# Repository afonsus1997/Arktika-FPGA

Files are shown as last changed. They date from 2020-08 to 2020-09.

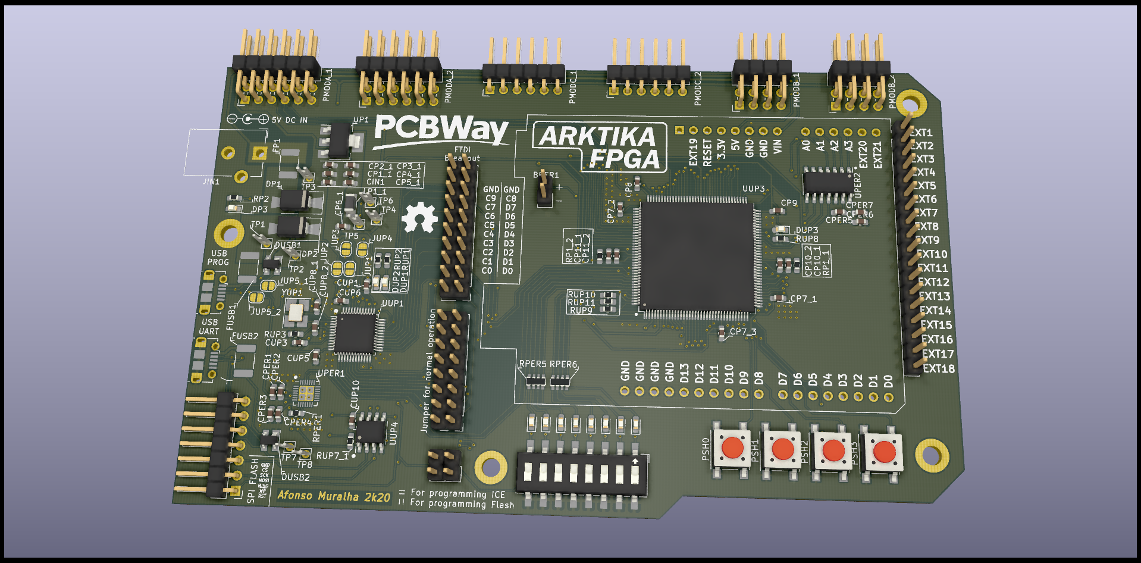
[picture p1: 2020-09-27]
Hardware/arktika-fpga/Media/render1.png

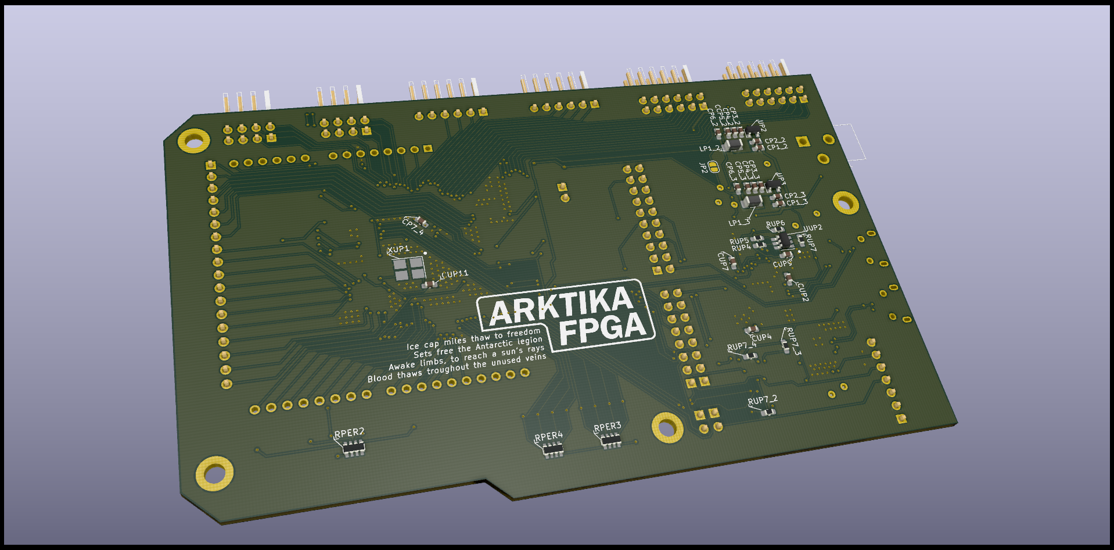
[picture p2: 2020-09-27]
Hardware/arktika-fpga/Media/render2.png

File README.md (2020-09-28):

Arktikalogo

### Project description

The Arktika FPGA is an open-source FPGA development board based on the ICE40 family (ICE40HX4K-TQ144).

### Main Features:

* 78 total user digital IO pins
  * 18 arduino uno compatible headers
  * 6 PMOD connectors (40 total pins)
    * 2x10pin
    * 2x6pin
    * 2x4pin
  * 18pin additional "EXT" connector
  * Buzzer connector
* 4 analog input channels
  * MCP3204 ADC
* 8 on-board LEDs
* 8 on-board DIP switches
* 4 on-board push buttons
* USB to UART bridge
* 50Mhz active crystal oscillator
* FT232hl USB bridge
  * Used for FPGA or flash programming
  * Breakout header for external use

### Known bugs
* V1.0
  * Flash CS line not connected (typo on net name)
  * Arduino connector mirrores (inteded for a shield and not the arduino footprint)
  * Wrong usb to uart bridge footprint (the footprint is correct, but it is not for the intended version of the IC)

### Development Log

* 27/09/20 (up to)
  * Finishing PCB design
  * Tested toolchain with some examples

### Screenshots and pictures

RenderFront

RanderBack

### Useful development links

[ICE40 Family datasheet](https://static6.arrow.com/aropdfconversion/5a93cb52911751cf0d102889c061f1e82d924150/3ice40lphxfamilydatasheet.pdf)

[ICE40 Hardware checklist](http://www.latticesemi.com/~/media/LatticeSemi/Documents/ApplicationNotes/IK/iCE40HardwareChecklist.pdf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)

[ICE40 Decoupling information](https://www.latticesemi.com/-/media/LatticeSemi/Documents/ApplicationNotes/PT/PowerDecouplingandBypassFilteringforProgrammableDevices.ashx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)

[ICE40 Programming information](http://www.latticesemi.com/dynamic/view_document.cfm?document_id=46502)

[PMOD Standard](http://digilentinc.com/Pmods/Digilent-Pmod_%20Interface_Specification.pdf)

###### Bonus

Q: What is arktika?

A: [Glad you asked!](https://en.wikipedia.org/wiki/Arktika_(1972_icebreaker))

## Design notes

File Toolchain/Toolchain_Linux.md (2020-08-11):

# Development Toolchain for linux

This document explains the development process for the Arktika FPGA
This document is a summary of the website 

Tools used:

* Yosys
    * For synthesis
* NextPNR
    * For Place and Route
* Icepack
    * For creating the bitstream
* Iceprog
    * For programing the FPGA/Flash

Special arguments for the iCE40-HX4K-TQ144 chip: 

  * nextpnr args:```--hx8k --package tq144:4k```
  * aranchne-pnr args:```-d 8k -P tq144:4k```
  * icetime args: ```-d hx8k```

### How to install the toolchain

Follow the instructions for [Summon-FPGA-Tools](https://github.com/esden/summon-fpga-tools). This will install all the needed tools.

### Toolchain usage example

Consider the (example name) example present on the examples folder.

* top.v
```
module top (input SW0, SW1, output LED0);
  assign LED0 = SW0 & SW1;
endmodule
```

The designators for the arktika io is present on the arktika.pcf file. This file must be included in the place and route process.

##### Using the command line:

* Synthesize the verilog code:
```
$ yosys -p 'synth_ice40 -top top -json top.json' top.v
```
* Do the place and route:
```
$ nextpnr-ice40 --hx8k --package tq144:4k  --pcf ../../Toolchain/arktika.pcf --json top.json --asc top.asc
```
* Create the bitstream
```
$ icepack top.asc top.bin
```
* Program the FPGA/Flash
```
$ iceprog top.bin
```

##### Using NextPNR GUI

* Synthesize the verilog code:
```
$ yosys -p 'synth_ice40 -top top -json top.json' top.v
```
* Do the place and route on the gui and export the .asc file:
```
$ nextpnr-ice40 --hx8k --package tq144:4k --json top.json --pcf ../../Toolchain/arktika.pcf --asc top.asc --gui
```
* Create the bitstream
```
$ icepack top.asc top.bin
```
* Program the FPGA/Flash
```
$ iceprog top.bin
```

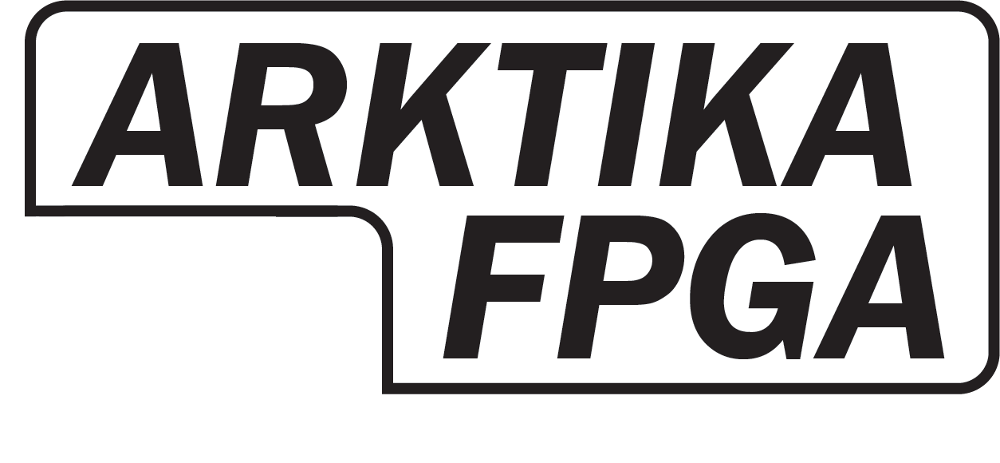
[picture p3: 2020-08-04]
Hardware/arktika-fpga/Media/arktikaFPGA_smaller.bmp

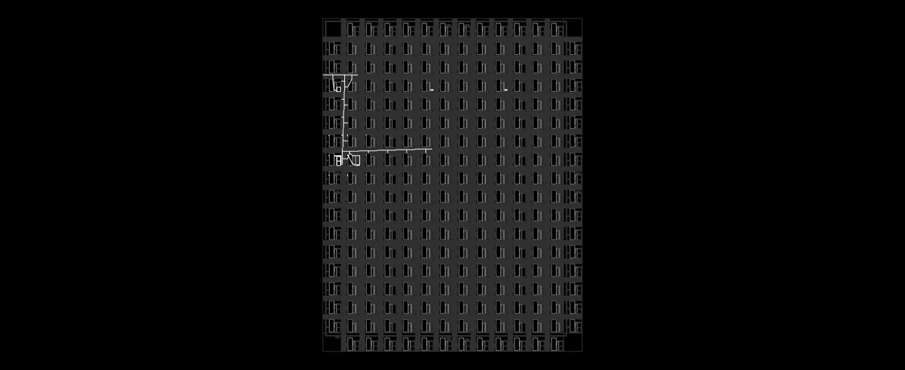
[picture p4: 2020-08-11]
Examples/Basic/top.png

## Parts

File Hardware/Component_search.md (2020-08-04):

### Power

Need 3.3V and 1.2V

* 3.3V
  * AMS1117
    * Have in stock, but may be too big/overkill
    * Gives some margin for driving more (and more demanding) external peripherals 

* 1.2V
  * MCP1812AT
    * 0.35eur
    * small
    * 300mA max
    * used on the icebreaker fpga and on the kefir fpga

### FPGA

Using the ICE40HX4K-TQ144

-----

# Component List

## Sheet Power

* JUSB1 - USB_B_ Micro – USB female connector.  <br>
  Datasheet:
  [Aliexpress](https://www.aliexpress.com/item/32795649371.html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,searchweb201602_,searchweb201603_) <br>
  
* DUSB1 – SP0503BAHT  - Array of protecting diodes.  <br>
  Datasheet:
  
* FUSB1 – Fuse for USB  <br>
  Datasheet:
  
* UP1 – AMS AMS1117-3.3   - Voltage Regulator 3.3V <br>
  [DigiKey](https://www.digikey.com/products/en/integrated-circuits-ics/pmic-display-drivers/729?k=AMS1117) <br>
  [Datasheet](https://media.digikey.com/pdf/Data%20Sheets/Austriamicrosystems%20PDFs/AS1117.pdf)
  
* UP2 e UP3 – Microchip MCP1812AT – Voltage Regulator 1.2V <br>
  [DigiKey](https://www.digikey.com/product-detail/en/microchip-technology/MCP1812AT-012-TT/MCP1812AT-012-TTTR-ND/9695617) <br>
  [Datasheet](https://ww1.microchip.com/downloads/en/DeviceDoc/MCP1811A-11B-12A-12B-Family-Data-Sheet-DS20006088C.pdf)
  
* LP1_1, LP1_2 e LP1_3 – Ferrite bead – High frequency filter. Murata BLM31B601S, BLM11B601SPB <br>
  [Mouser Electronics]()  <br>
  [Datasheet](https://pt.mouser.com/datasheet/2/281/c31e-794748.pdf)
                
## Sheet USB AND PROG

* Y? - 12 MHz Crystal <br>
  Datasheet:
  
* UUP1 – FTDI FT232H – USB to serial and SPI converter 3.3V. <br>
  [DigiKey](https://www.digikey.com/product-detail/en/ftdi-future-technology-devices-international-ltd/FT232HL-REEL/768-1101-1-ND/2614632) <br>
  [Datasheet](https://www.ftdichip.com/Support/Documents/DataSheets/ICs/DS_FT232H.pdf)
  
* UUP2 –  EEPROM 93LC56BT-I/OT – EEPROM to retain the configurations for the FTDI USB serial and SPI converter. <br>
  [DigiKey]( https://www.digikey.pt/product-detail/en/microchip-technology/93LC56BT-I-OT/93LC56BT-I-OTTR-ND/572825 )  <br>
  [Datasheet]( https://static6.arrow.com/aropdfconversion/88ae318f18f89e8680c0097a6b922f08efb41928/21794g.pdf )
  
* UP3E – FPGA LATICE ICE40HX4K-TQ144 <br>
  [DigiKey](https://www.digikey.com/products/en?keywords=ICE40HX4K-TQ144) <br>
  [Datasheet]()
  
* UUP4 – FLASH memory Winbond Electronics W25Q128JVS 3.3V- Flash to where is stored the FPGA configuration.<br>
  [DigiKey](https://www.digikey.com/product-detail/en/winbond-electronics/W25Q128JVSIQ-TR/W25Q128JVSIQTR-ND/5803944) <br>
  [Datasheet](https://www.winbond.com/resource-files/w25q128jv%20revf%2003272018%20plus.pdf)
                
## Sheet FPGA_IO
* Interfaces PMOD <br>
  PMOD1 – 2x10 <br>
  PMOD2 – 2x6 <br>
  PMOD3 – 2x4 <br>
  [Datasheet]()
* Interface Arduino UNO R3
* Interface common PINs FPGA
* Crystal oscillator ([arrow](https://www.arrow.com/en/products/abm8-50.000mhz-b1u-t/abracon), [arrow](https://www.arrow.com/en/products/ecs-500-10-33-rtn-tr/ecs-international), [arrow](https://www.arrow.com/en/products/7m-50.000maaj-t/txc-corporation), [arrow](https://www.arrow.com/en/products/ase2-50.000mhz-et/abracon), [arrow](https://www.arrow.com/en/products/ase2-50.000mhz-et/abracon))

## Sheet FPGA_PERIPHS

* JUSB2 – USB_B_MICRO – 2º USB female connector for serial to USB output/input. <br>
  Datasheet:
  
* U? - Silicon Labs CP2102N-A01-GQFN28 – 2º Converter USB Serial 3.3V. (end of life component) <br>
  [DigiKey](https://www.digikey.com/product-detail/en/silicon-labs/CP2102N-A01-GQFN28/336-3694-ND/6012519) <br>
  [Datasheet](https://media.digikey.com/pdf/Data%20Sheets/Silicon%20Laboratories%20PDFs/CP2102N_Rev.1.3_DS.pdf)
  
* U? – Microchip ADC  MCP3204 – 12 bit’s ADC, 100KS/s, 4 channels, SPI. <br>
  [Digikey](https://www.digikey.com/product-detail/en/microchip-technology/MCP3204-CI-SL/MCP3204-CI-SL-ND/305927) <br>
  [Datasheet](https://www.digikey.com/htmldatasheets/production/48382/0/0/1/mcp3204-3208.html)

* SW? – SW_DIP_x08 <br>
  Datasheet:
  
* And several resistors arrays.

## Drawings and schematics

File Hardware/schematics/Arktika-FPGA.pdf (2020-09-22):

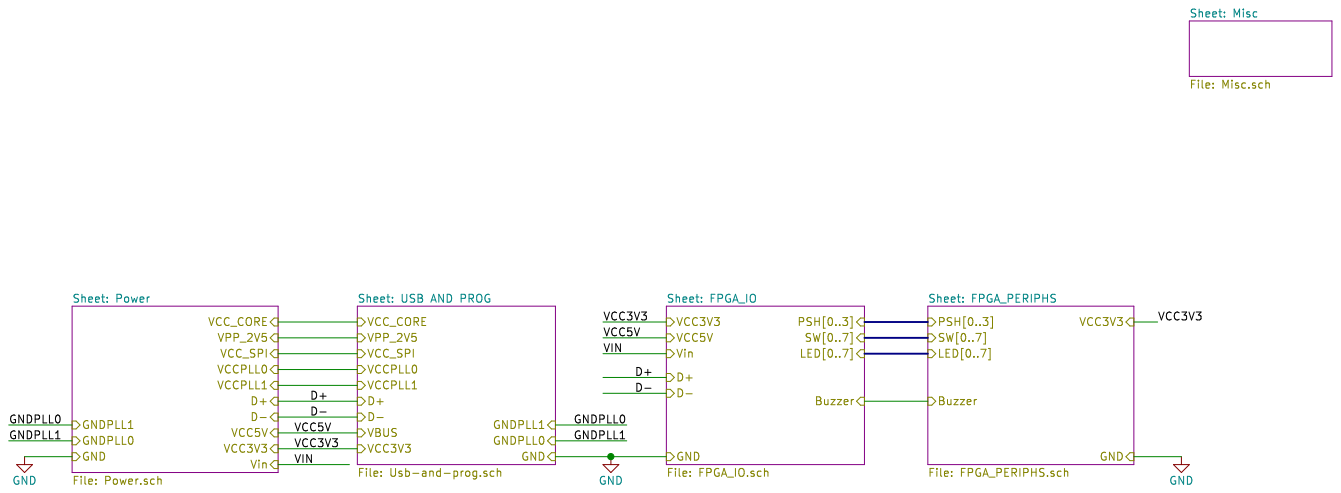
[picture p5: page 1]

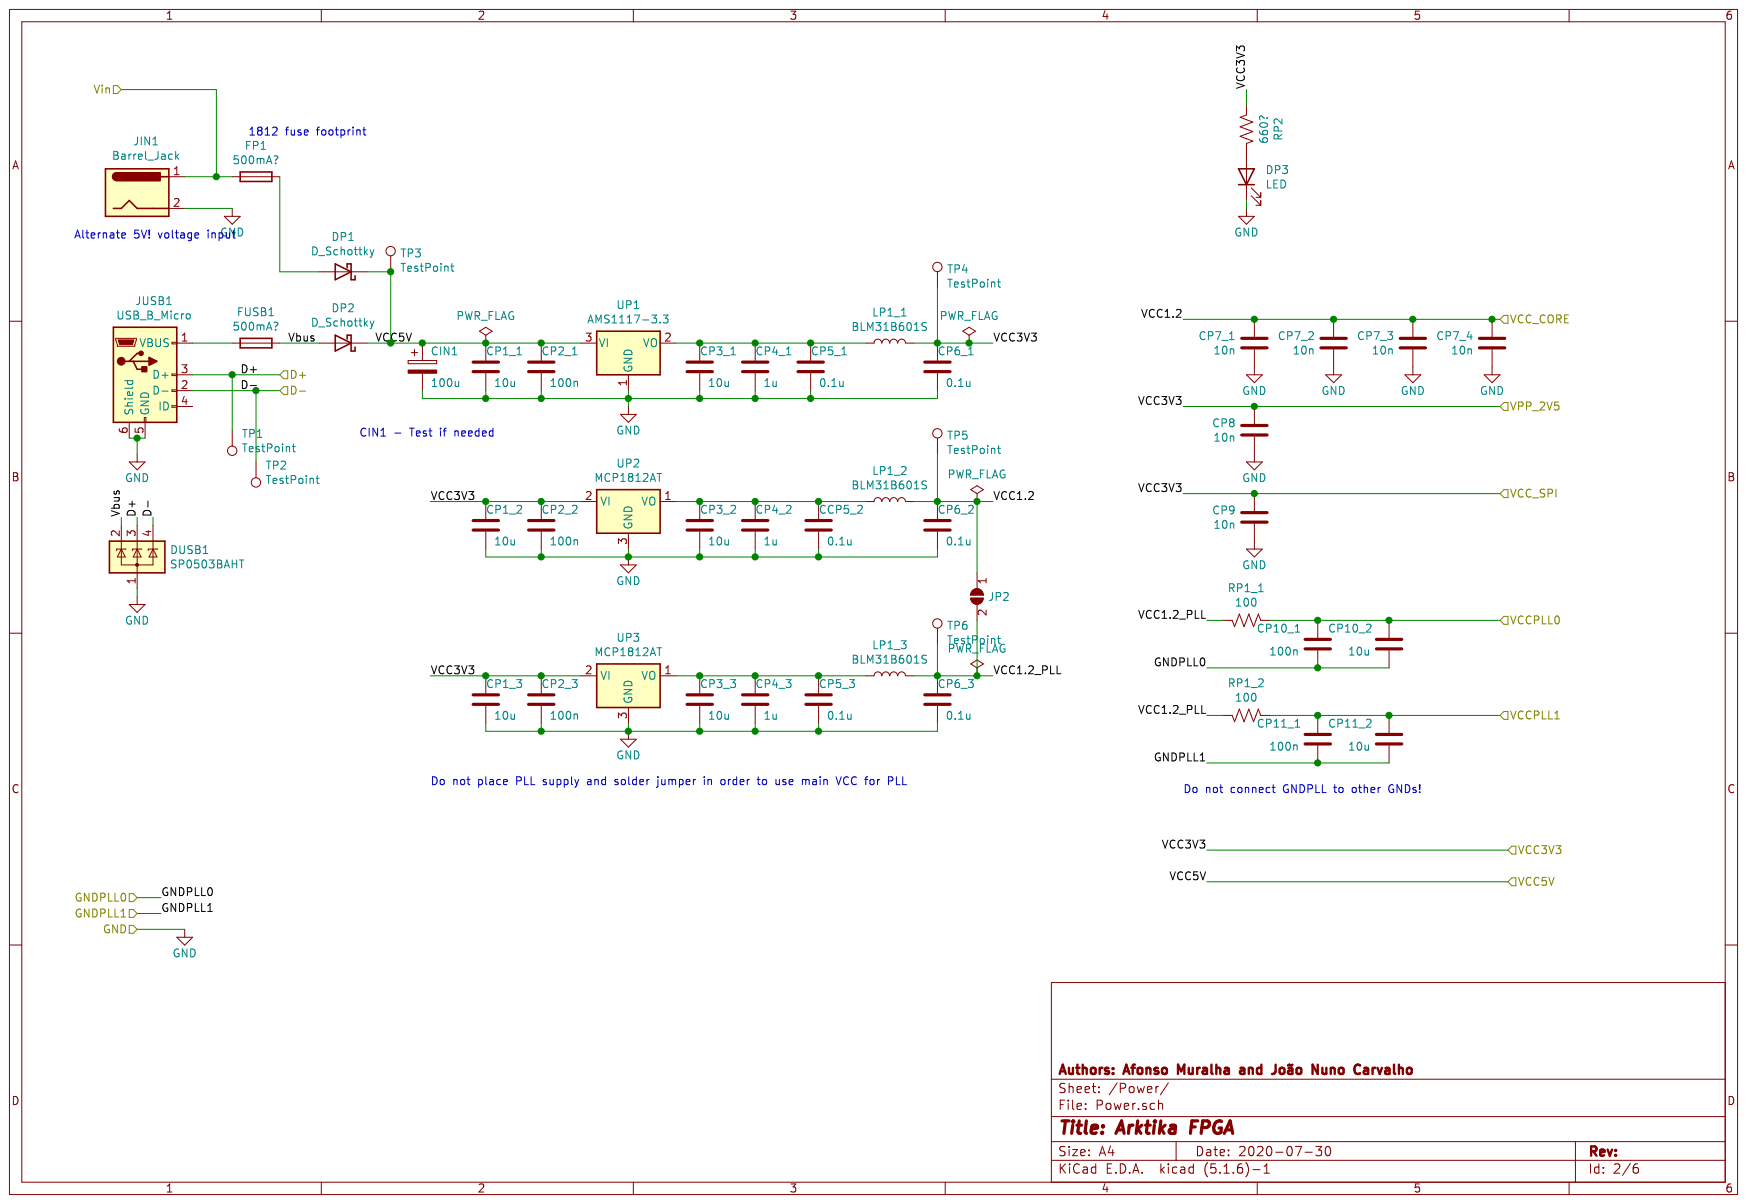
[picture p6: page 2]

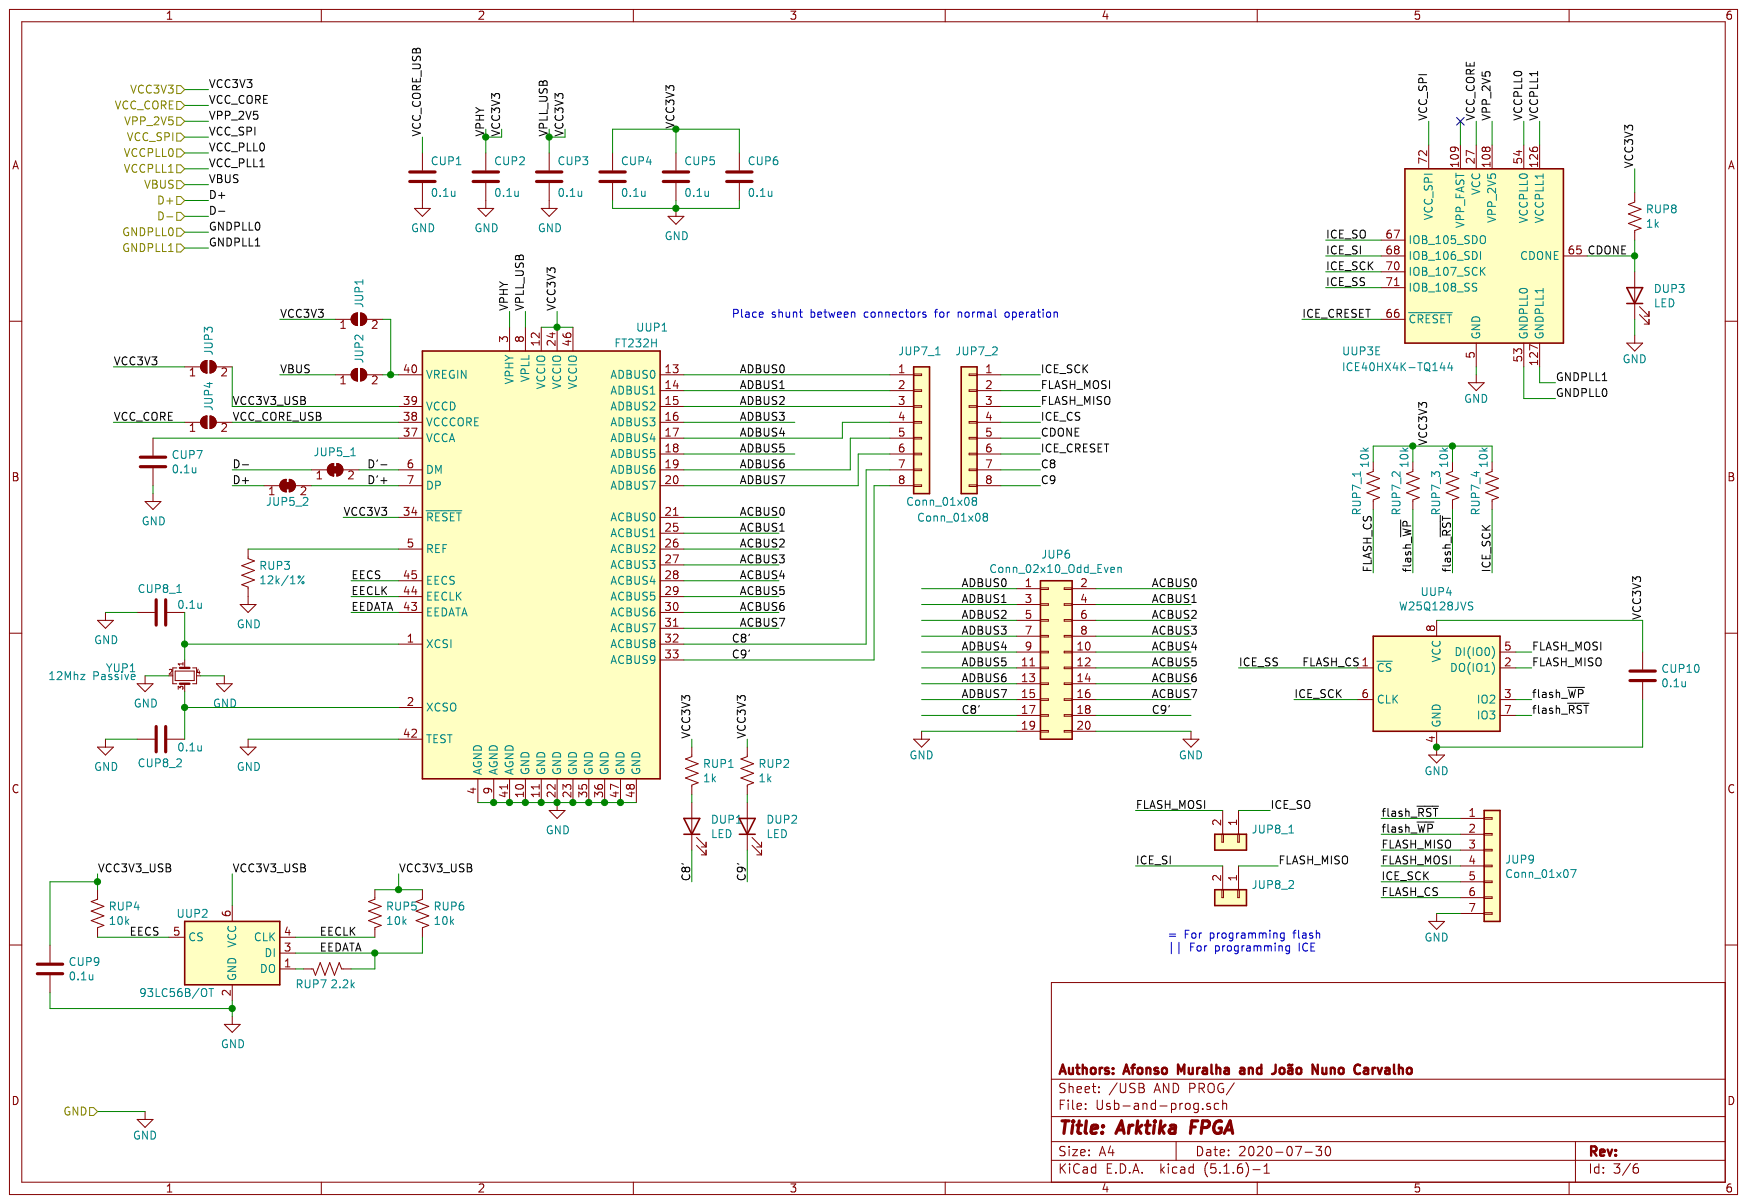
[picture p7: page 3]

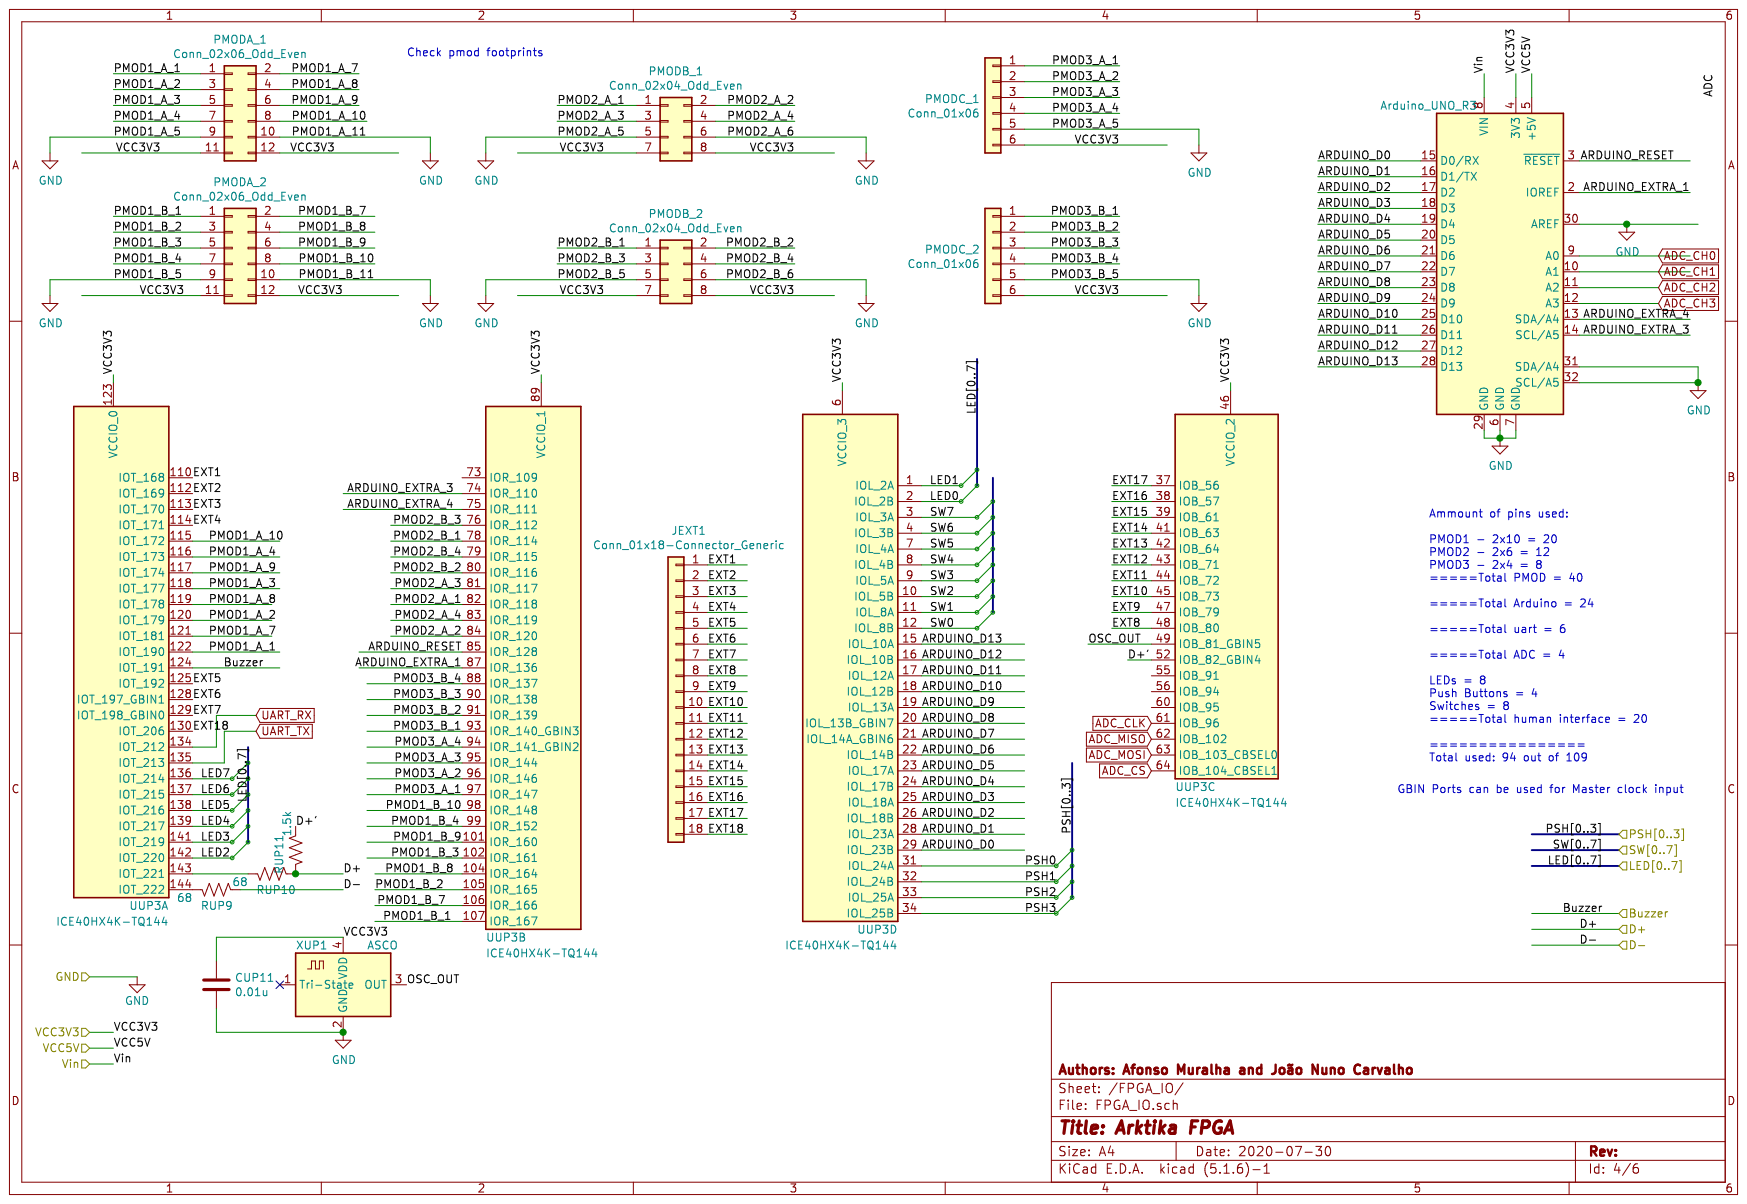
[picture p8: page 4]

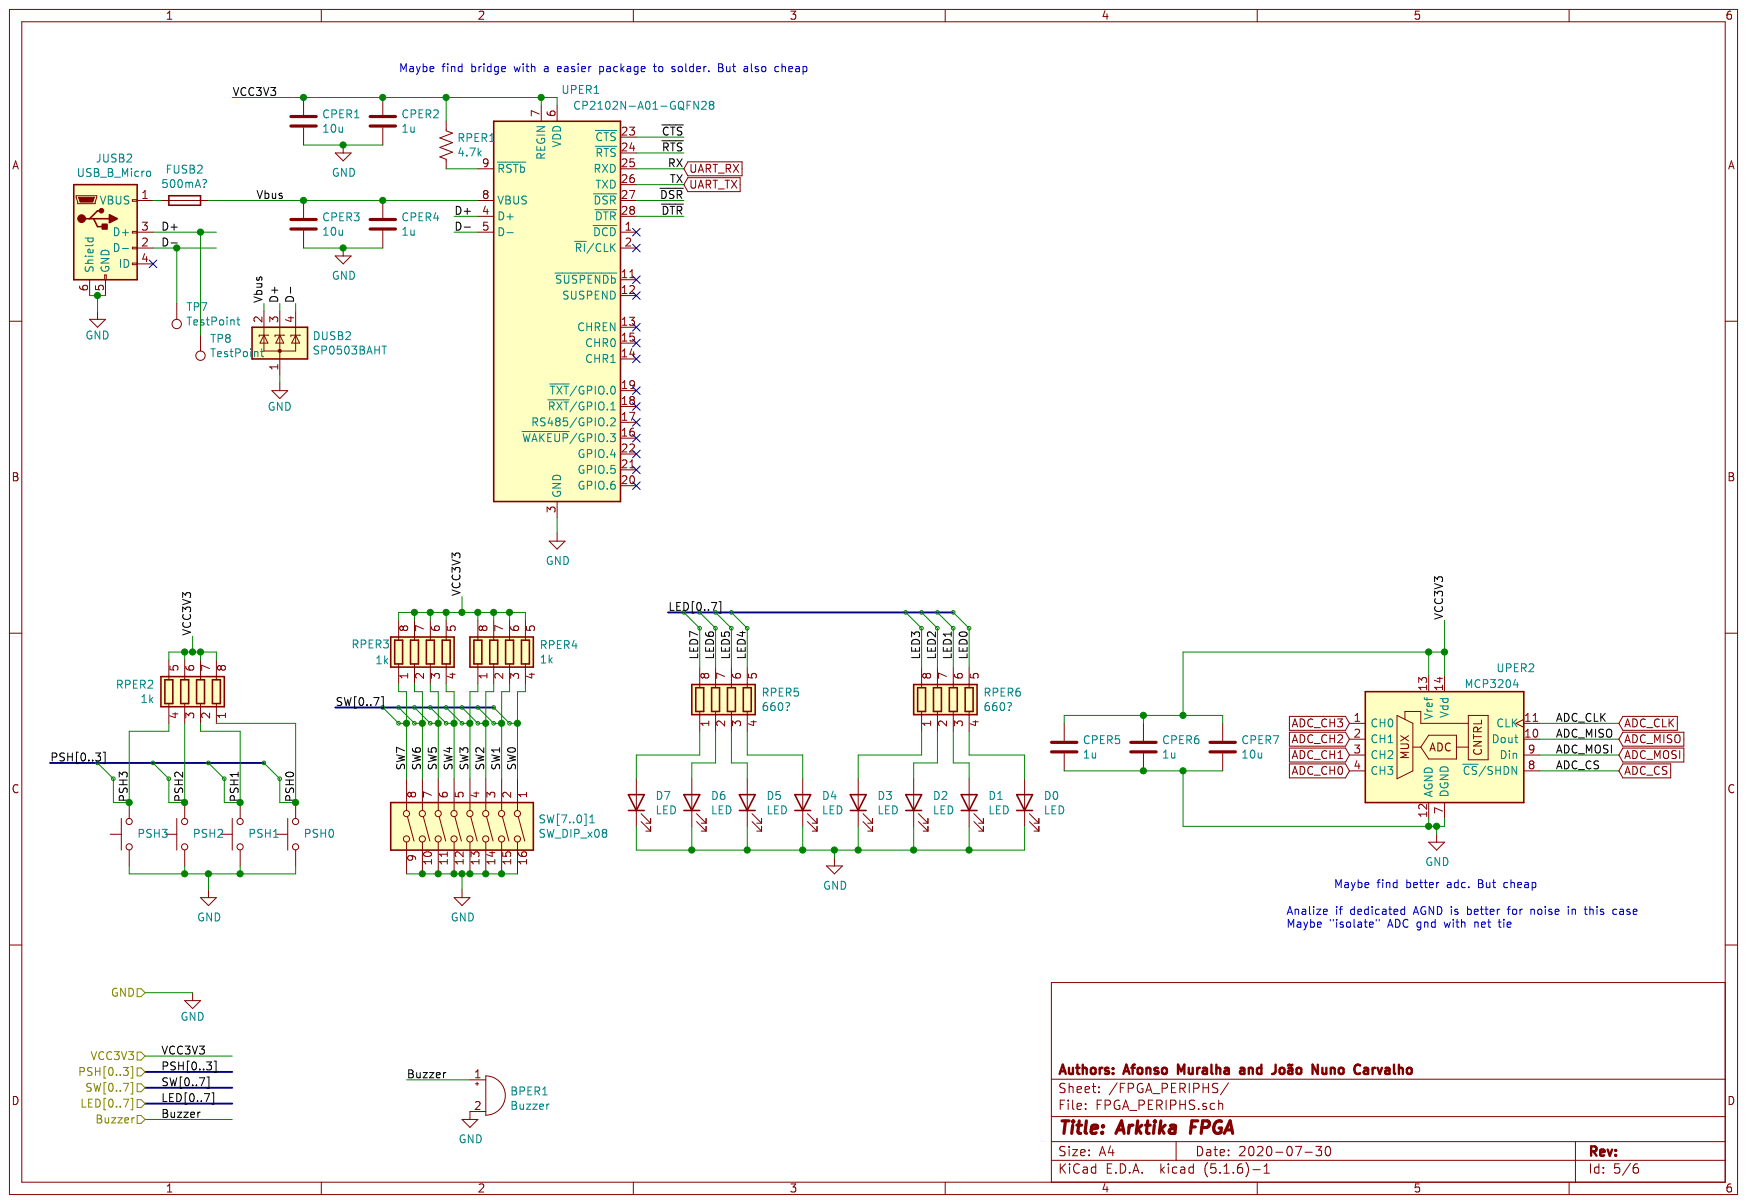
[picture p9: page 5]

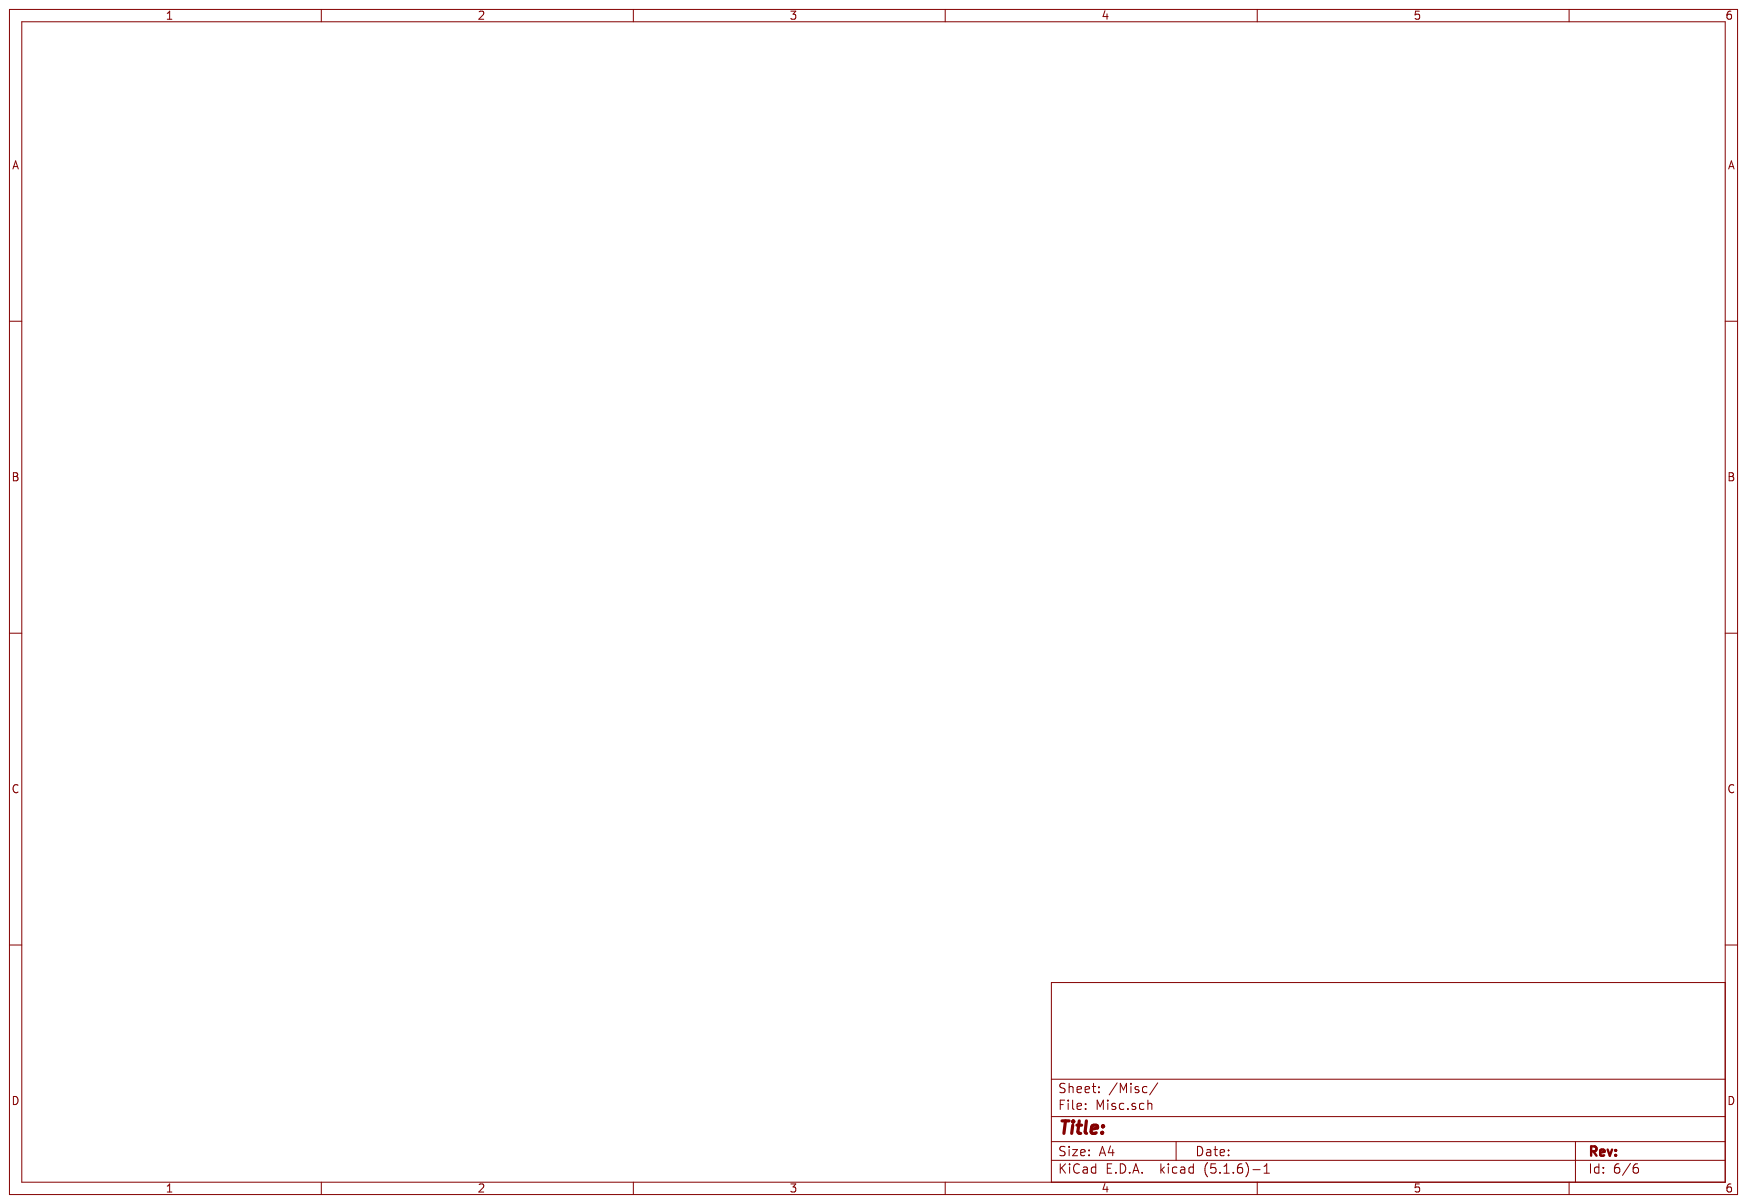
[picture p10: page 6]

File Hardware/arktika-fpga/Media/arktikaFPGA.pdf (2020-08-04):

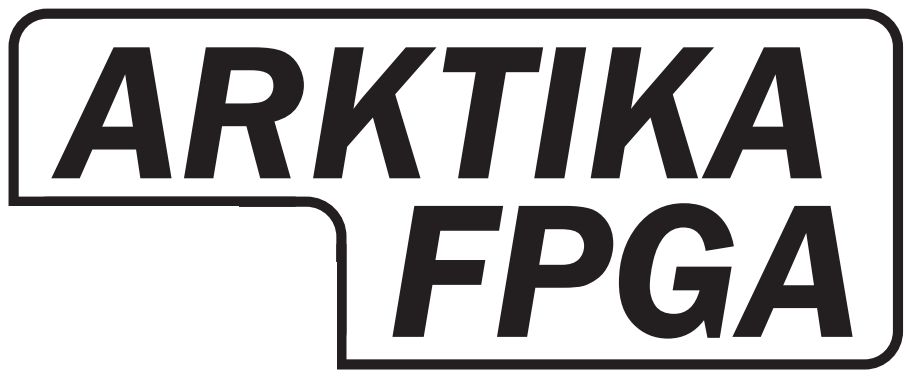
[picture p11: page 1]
ARKTIKA FPGA

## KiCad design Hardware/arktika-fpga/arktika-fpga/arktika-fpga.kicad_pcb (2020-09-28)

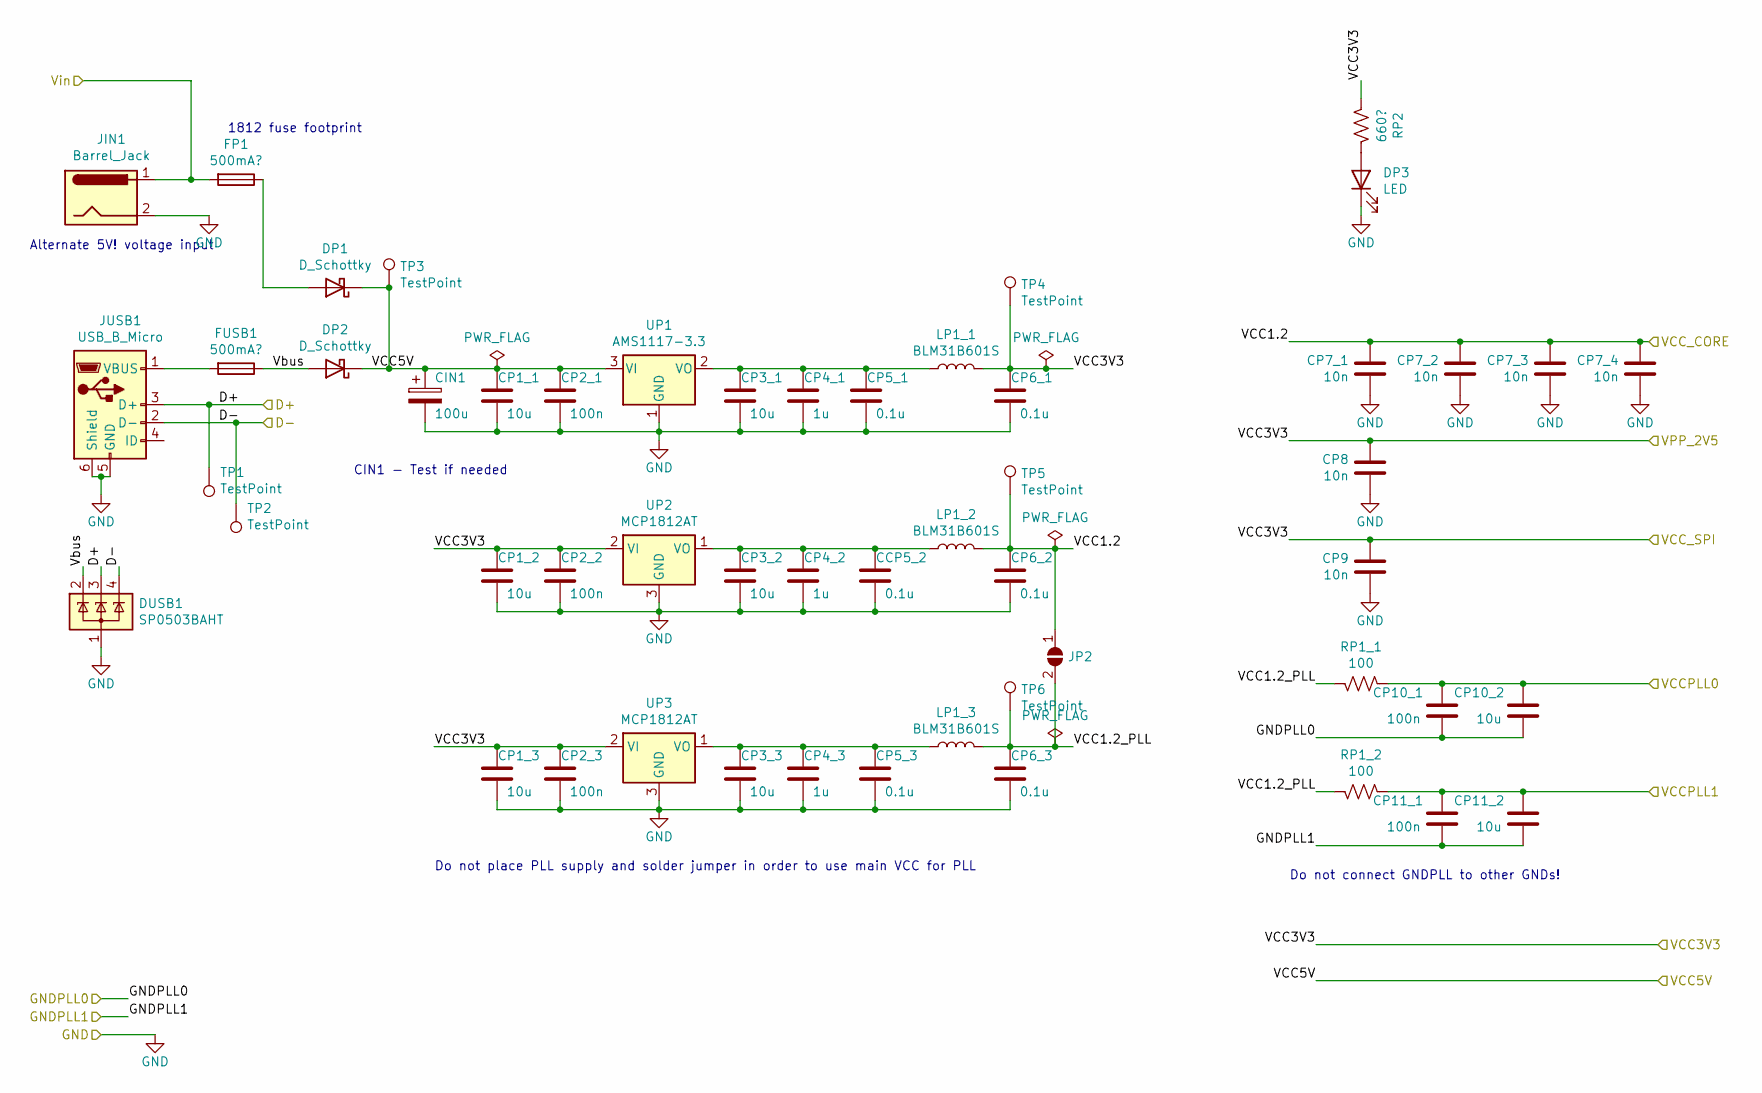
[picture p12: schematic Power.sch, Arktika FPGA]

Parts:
CCP5_2: 0.1u; C_0603_1608Metric_Pad1.05x0.95mm_HandSolder
CIN1: 100u; C_0603_1608Metric_Pad1.05x0.95mm_HandSolder
CP1_1, CP1_2, CP1_3, CP3_1, CP3_2, CP3_3, CP10_2, CP11_2: 10u; C_0603_1608Metric_Pad1.05x0.95mm_HandSolder
CP2_1, CP2_2, CP2_3, CP10_1, CP11_1: 100n; C_0603_1608Metric_Pad1.05x0.95mm_HandSolder
CP4_1, CP4_2, CP4_3: 1u; C_0603_1608Metric_Pad1.05x0.95mm_HandSolder
CP5_1, CP5_3, CP6_1, CP6_2, CP6_3: 0.1u; C_0603_1608Metric_Pad1.05x0.95mm_HandSolder
CP7_1, CP7_2, CP7_3, CP7_4, CP8, CP9: 10n; C_0603_1608Metric_Pad1.05x0.95mm_HandSolder
DP1, DP2: D_Schottky; D_SMA-SMB_Universal_Handsoldering
DP3: LED; LED_0603_1608Metric_Pad1.05x0.95mm_HandSolder
DUSB1: SP0503BAHT; SOT-143
FP1: 500mA?; Fuse_1812_4532Metric_Pad1.30x3.40mm_HandSolder
FUSB1: 500mA?; Fuse_1812_4532Metric_Pad1.30x3.40mm_HandSolder
JIN1: Barrel_Jack; Barrel_Jack_CUI_PJ-102AH
JP2: SolderJumper_2_Open; SolderJumper-2_P1.3mm_Open_RoundedPad1.0x1.5mm
JUSB1: USB_B_Micro; USB_Micro-B_Molex-105017-0001
LP1_1, LP1_2, LP1_3: BLM31B601S; L_1206_3216Metric_Pad1.42x1.75mm_HandSolder
RP1_1, RP1_2: 100; R_0603_1608Metric_Pad1.05x0.95mm_HandSolder
RP2: 660?; R_0603_1608Metric_Pad1.05x0.95mm_HandSolder
TP1, TP2, TP3, TP4, TP5, TP6: TestPoint; Pin_D0.7mm_L6.5mm_W1.8mm_FlatFork
UP1: AMS1117-3.3; SOT-223-3_TabPin2
UP2, UP3: MCP1812AT; SOT-23

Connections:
/D+: DUSB1.3 (K), JUSB1.3 (D+), TP1.1; also elsewhere on the board
/D-: DUSB1.4 (K), JUSB1.2 (D-), TP2.1; also elsewhere on the board
/GNDPLL0: CP11_1.2, CP11_2.2; also elsewhere on the board
/GNDPLL1: CP10_1.2, CP10_2.2; also elsewhere on the board
/Power/VCC1.2_PLL: CP6_3.1, JP2.2 (B), LP1_3.2, RP1_1.1, RP1_2.1, TP6.1
/Power/VCCPLL0: CP10_1.1, CP10_2.1, RP1_1.2; also elsewhere on the board
/Power/VCCPLL1: CP11_1.1, CP11_2.1, RP1_2.2; also elsewhere on the board
/Power/VCC_CORE: CP6_2.1, CP7_1.1, CP7_2.1, CP7_3.1, CP7_4.1, JP2.1 (A), LP1_2.2, TP5.1; also elsewhere on the board
/Power/Vbus: DP2.2 (A), DUSB1.2 (K), FUSB1.1
/VCC3V3: CP1_2.1, CP1_3.1, CP2_2.1, CP2_3.1, CP6_1.1, CP8.1, CP9.1, LP1_1.2, RP2.1, TP4.1, UP2.2 (VI), UP3.2 (VI); also elsewhere on the board
/VCC5V: CIN1.1, CP1_1.1, CP2_1.1, DP1.1 (K), DP2.1 (K), TP3.1, UP1.3 (VI); also elsewhere on the board
/VIN: FP1.2, JIN1.1; also elsewhere on the board
GND: CCP5_2.2, CIN1.2, CP1_1.2, CP1_2.2, CP1_3.2, CP2_1.2, CP2_2.2, CP2_3.2, CP3_1.2, CP3_2.2, CP3_3.2, CP4_1.2, CP4_2.2, CP4_3.2, CP5_1.2, CP5_3.2, CP6_1.2, CP6_2.2, CP6_3.2, CP7_1.2, CP7_2.2, CP7_3.2, CP7_4.2, CP8.2, CP9.2, DP3.1 (K), DUSB1.1 (A), JIN1.2, JUSB1.5 (GND), JUSB1.6 (Shield), UP1.1 (GND), UP2.3 (GND), UP3.3 (GND); also elsewhere on the board
unnamed: CCP5_2.1, CP3_2.1, CP4_2.1, LP1_2.1, UP2.1 (VO)
unnamed: CP3_1.1, CP4_1.1, CP5_1.1, LP1_1.1, UP1.2 (VO)
unnamed: CP3_3.1, CP4_3.1, CP5_3.1, LP1_3.1, UP3.1 (VO)
unnamed: DP1.2 (A), FP1.1
unnamed: DP3.2 (A), RP2.2
unnamed: FUSB1.2, JUSB1.1 (VBUS)

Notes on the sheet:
Do not connect GNDPLL to other GNDs!
Do not place PLL supply and solder jumper in order to use main VCC for PLL
CIN1 - Test if needed
Alternate 5V! voltage input
1812 fuse footprint

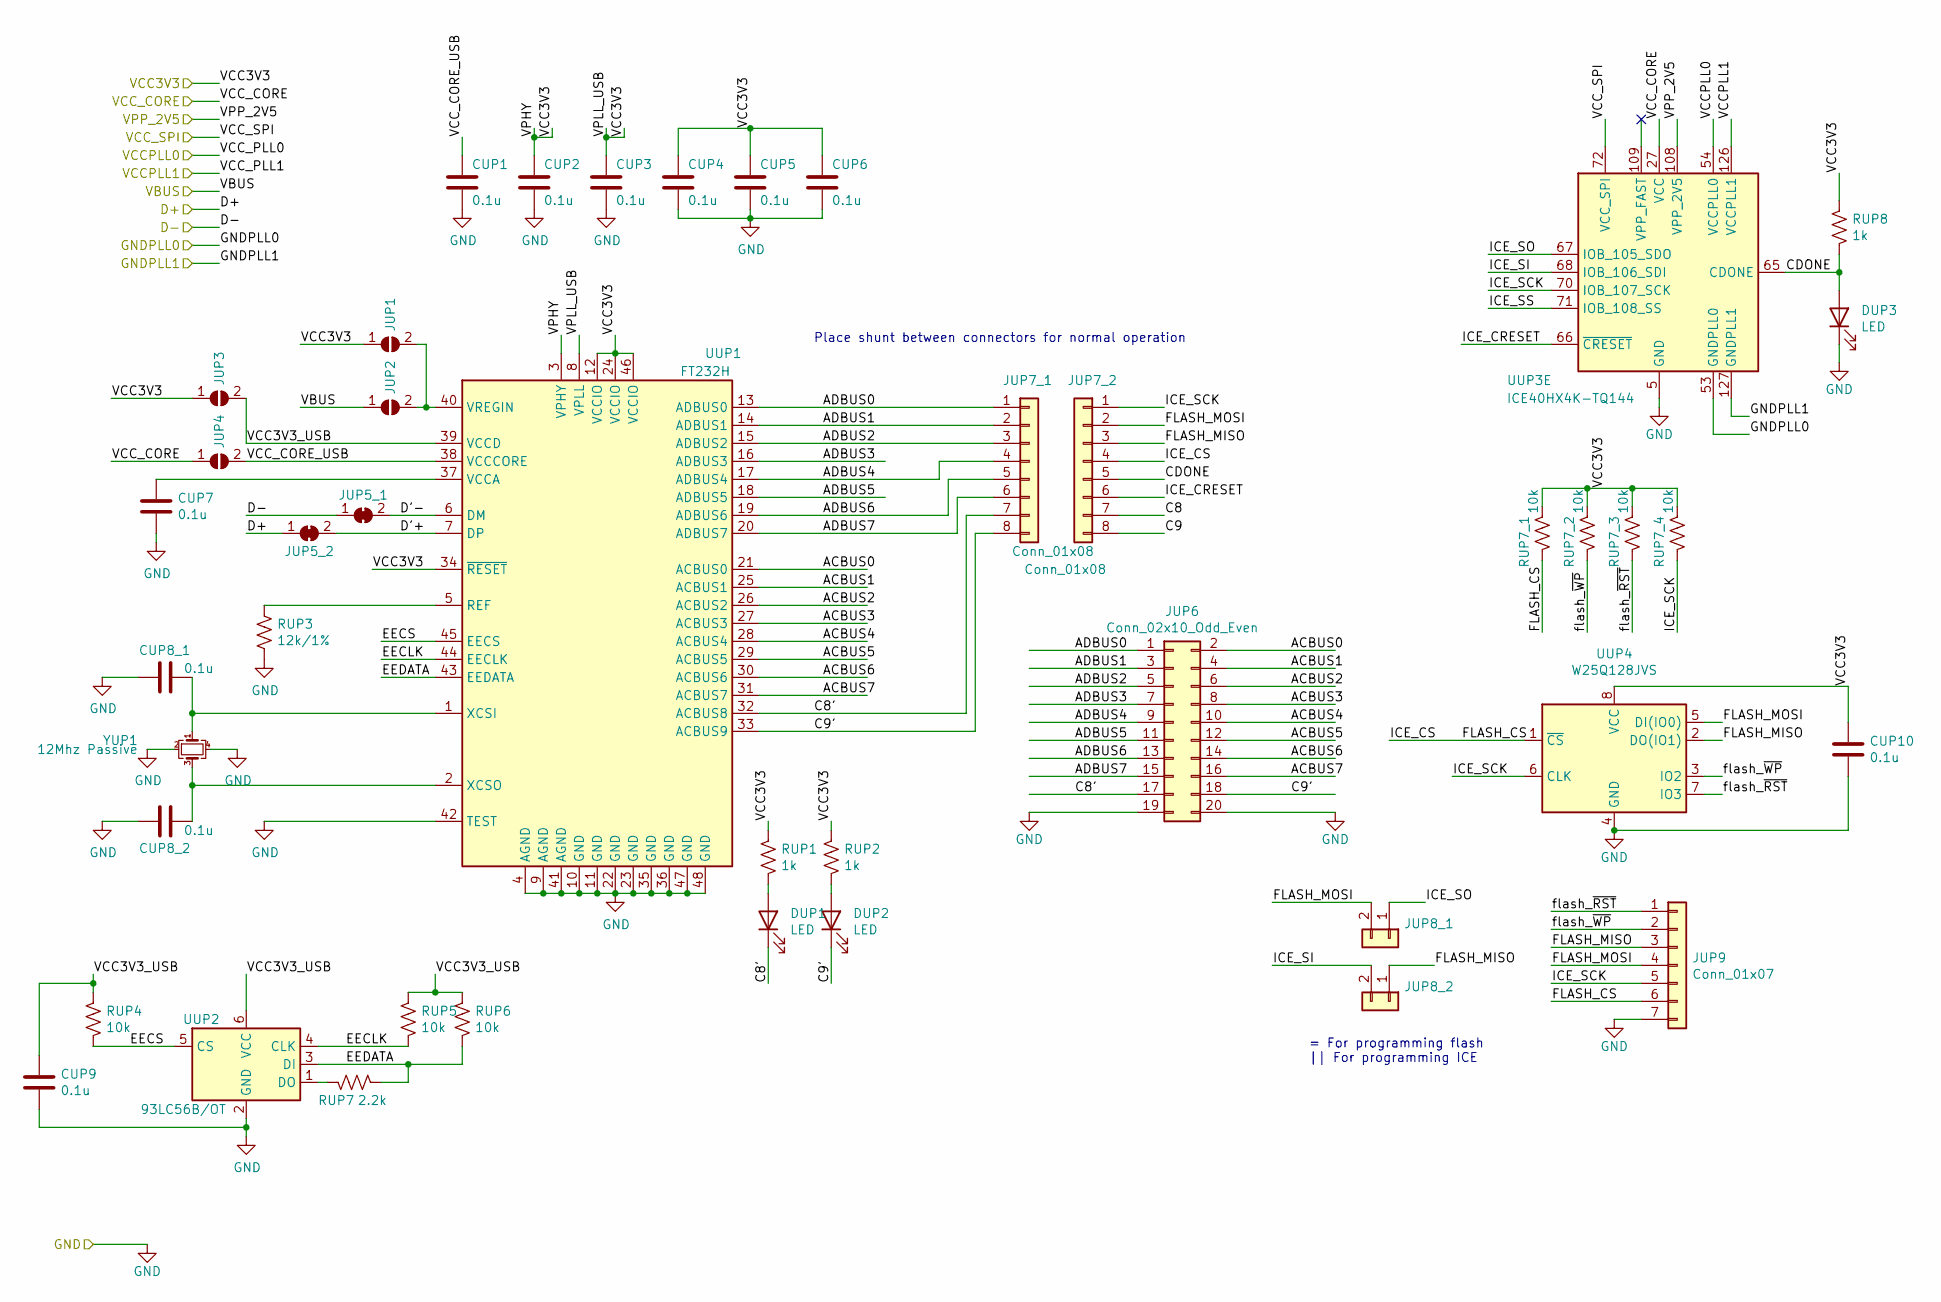
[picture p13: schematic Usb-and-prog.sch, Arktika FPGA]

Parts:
CUP1, CUP2, CUP3, CUP4, CUP5, CUP6, CUP7, CUP8_1, CUP8_2, CUP9, CUP10: 0.1u; C_0603_1608Metric_Pad1.05x0.95mm_HandSolder
DUP1, DUP2, DUP3: LED; LED_0603_1608Metric_Pad1.05x0.95mm_HandSolder
JUP1, JUP2, JUP3, JUP4: SolderJumper_2_Open; SolderJumper-2_P1.3mm_Open_RoundedPad1.0x1.5mm
JUP5_1, JUP5_2: SolderJumper_2_Bridged; SolderJumper-2_P1.3mm_Bridged2Bar_RoundedPad1.0x1.5mm
JUP6: Conn_02x10_Odd_Even; PinHeader_2x10_P2.54mm_Vertical
JUP7_1, JUP7_2: Conn_01x08; Pin_Header_Straight_1x08_Pitch2.54mm
JUP8_1, JUP8_2: Conn_01x02; Pin_Header_Straight_1x02_Pitch2.54mm
JUP9: Conn_01x07; PinHeader_1x07_P2.54mm_Horizontal
RUP1, RUP2, RUP8: 1k; R_0603_1608Metric_Pad1.05x0.95mm_HandSolder
RUP3: 12k/1%; R_0603_1608Metric_Pad1.05x0.95mm_HandSolder
RUP4, RUP5, RUP6, RUP7_1, RUP7_2, RUP7_3, RUP7_4: 10k; R_0603_1608Metric_Pad1.05x0.95mm_HandSolder
RUP7: 2.2k; R_0603_1608Metric_Pad1.05x0.95mm_HandSolder
UUP1: FT232H; LQFP-48-1EP_7x7mm_P0.5mm_EP3.6x3.6mm
UUP2: 93LC56B/OT; SOT-23-6_Handsoldering
UUP3: ICE40HX4K-TQ144; TQFP-144_20x20mm_P0.5mm
UUP4: W25Q128JVS; SOIC-8_3.9x4.9mm_P1.27mm
YUP1: 12Mhz Passive; Crystal_SMD_3225-4Pin_3.2x2.5mm_HandSoldering

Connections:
/D+: JUP5_2.1 (A); also elsewhere on the board
/D-: JUP5_1.1 (A); also elsewhere on the board
/GNDPLL0: UUP3.127 (GNDPLL1); also elsewhere on the board
/GNDPLL1: UUP3.53 (GNDPLL0); also elsewhere on the board
/Power/VCCPLL0: UUP3.54 (VCCPLL0); also elsewhere on the board
/Power/VCCPLL1: UUP3.126 (VCCPLL1); also elsewhere on the board
/Power/VCC_CORE: JUP4.1 (A), UUP3.27 (VCC), UUP3.40 (VCC), UUP3.92 (VCC), UUP3.111 (VCC); also elsewhere on the board
/USB AND PROG/ACBUS0: JUP6.2, UUP1.21 (ACBUS0)
/USB AND PROG/ACBUS1: JUP6.4, UUP1.25 (ACBUS1)
/USB AND PROG/ACBUS2: JUP6.6, UUP1.26 (ACBUS2)
/USB AND PROG/ACBUS3: JUP6.8, UUP1.27 (ACBUS3)
/USB AND PROG/ACBUS4: JUP6.10, UUP1.28 (ACBUS4)
/USB AND PROG/ACBUS5: JUP6.12, UUP1.29 (ACBUS5)
/USB AND PROG/ACBUS6: JUP6.14, UUP1.30 (ACBUS6)
/USB AND PROG/ACBUS7: JUP6.16, UUP1.31 (ACBUS7)
/USB AND PROG/ADBUS0: JUP6.1, JUP7_1.1, UUP1.13 (ADBUS0)
/USB AND PROG/ADBUS1: JUP6.3, JUP7_1.2, UUP1.14 (ADBUS1)
/USB AND PROG/ADBUS2: JUP6.5, JUP7_1.3, UUP1.15 (ADBUS2)
/USB AND PROG/ADBUS3: JUP6.7, UUP1.16 (ADBUS3)
/USB AND PROG/ADBUS4: JUP6.9, JUP7_1.4, UUP1.17 (ADBUS4)
/USB AND PROG/ADBUS5: JUP6.11, UUP1.18 (ADBUS5)
/USB AND PROG/ADBUS6: JUP6.13, JUP7_1.5, UUP1.19 (ADBUS6)
/USB AND PROG/ADBUS7: JUP6.15, JUP7_1.6, UUP1.20 (ADBUS7)
/USB AND PROG/C8: JUP7_2.7
/USB AND PROG/C8': DUP1.1 (K), JUP6.17, JUP7_1.7, UUP1.32 (ACBUS8)
/USB AND PROG/C9: JUP7_2.8
/USB AND PROG/C9': DUP2.1 (K), JUP6.18, JUP7_1.8, UUP1.33 (ACBUS9)
/USB AND PROG/CDONE: DUP3.2 (A), JUP7_2.5, RUP8.2, UUP3.65 (CDONE)
/USB AND PROG/D'+: JUP5_2.2 (B), UUP1.7 (DP)
/USB AND PROG/D'-: JUP5_1.2 (B), UUP1.6 (DM)
/USB AND PROG/EECLK: RUP5.2, UUP1.44 (EECLK), UUP2.4 (CLK)
/USB AND PROG/EECS: RUP4.2, UUP1.45 (EECS), UUP2.5 (CS)
/USB AND PROG/EEDATA: RUP6.2, RUP7.1, UUP1.43 (EEDATA), UUP2.3 (DI)
/USB AND PROG/FLASH_MISO: JUP7_2.3, JUP8_2.1, JUP9.3, UUP4.2 (DO(IO1))
/USB AND PROG/FLASH_MOSI: JUP7_2.2, JUP8_1.2, JUP9.4, UUP4.5 (DI(IO0))
/USB AND PROG/ICE_CRESET: JUP7_2.6, UUP3.66 (~CRESET)
/USB AND PROG/ICE_SCK: JUP7_2.1, JUP9.5, RUP7_4.2, UUP3.70 (IOB_107_SCK), UUP4.6 (CLK)
/USB AND PROG/ICE_SI: JUP8_2.2, UUP3.68 (IOB_106_SDI)
/USB AND PROG/ICE_SO: JUP8_1.1, UUP3.67 (IOB_105_SDO)
/USB AND PROG/VCC3V3_USB: CUP9.1, JUP3.2 (B), RUP4.1, RUP5.1, RUP6.1, UUP1.39 (VCCD), UUP2.6 (VCC)
/USB AND PROG/VCC_CORE_USB: CUP1.1, JUP4.2 (B), UUP1.38 (VCCCORE)
/USB AND PROG/flash_~RST: JUP9.1, RUP7_3.2, UUP4.7 (IO3)
/USB AND PROG/flash_~WP: JUP9.2, RUP7_2.2, UUP4.3 (IO2)
/VCC3V3: CUP2.1, CUP3.1, CUP4.1, CUP5.1, CUP6.1, CUP10.1, JUP1.1 (A), JUP3.1 (A), RUP1.1, RUP2.1, RUP7_1.1, RUP7_2.1, RUP7_3.1, RUP7_4.1, RUP8.1, UUP1.3 (VPHY), UUP1.8 (VPLL), UUP1.12 (VCCIO), UUP1.24 (VCCIO), UUP1.34 (~RESET), UUP1.46 (VCCIO), UUP3.72 (VCC_SPI), UUP3.108 (VPP_2V5), UUP4.8 (VCC); also elsewhere on the board
/VCC5V: JUP2.1 (A); also elsewhere on the board
GND: CUP1.2, CUP2.2, CUP3.2, CUP4.2, CUP5.2, CUP6.2, CUP7.2, CUP8_1.2, CUP8_2.2, CUP9.2, CUP10.2, DUP3.1 (K), JUP6.19, JUP6.20, JUP9.7, RUP3.2, UUP1.4 (AGND), UUP1.9 (AGND), UUP1.10 (GND), UUP1.11 (GND), UUP1.22 (GND), UUP1.23 (GND), UUP1.35 (GND), UUP1.36 (GND), UUP1.41 (AGND), UUP1.42 (TEST), UUP1.47 (GND), UUP1.48 (GND), UUP2.2 (GND), UUP3.5 (GND), UUP3.13 (GND), UUP3.14 (GND), UUP3.59 (GND), UUP3.69 (GND), UUP3.86 (GND), UUP3.103 (GND), UUP3.132 (GND), UUP3.140 (GND), UUP4.4 (GND), YUP1.2, YUP1.4; also elsewhere on the board
unnamed: CUP7.1, UUP1.37 (VCCA)
unnamed: CUP8_1.1, UUP1.1 (XCSI), YUP1.1
unnamed: CUP8_2.1, UUP1.2 (XCSO), YUP1.3
unnamed: DUP1.2 (A), RUP1.2
unnamed: DUP2.2 (A), RUP2.2
unnamed: JUP1.2 (B), JUP2.2 (B), UUP1.40 (VREGIN)
unnamed: RUP3.1, UUP1.5 (REF)
unnamed: RUP7.2, UUP2.1 (DO)

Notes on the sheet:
= For programming flash || For programming ICE
Place shunt between connectors for normal operation

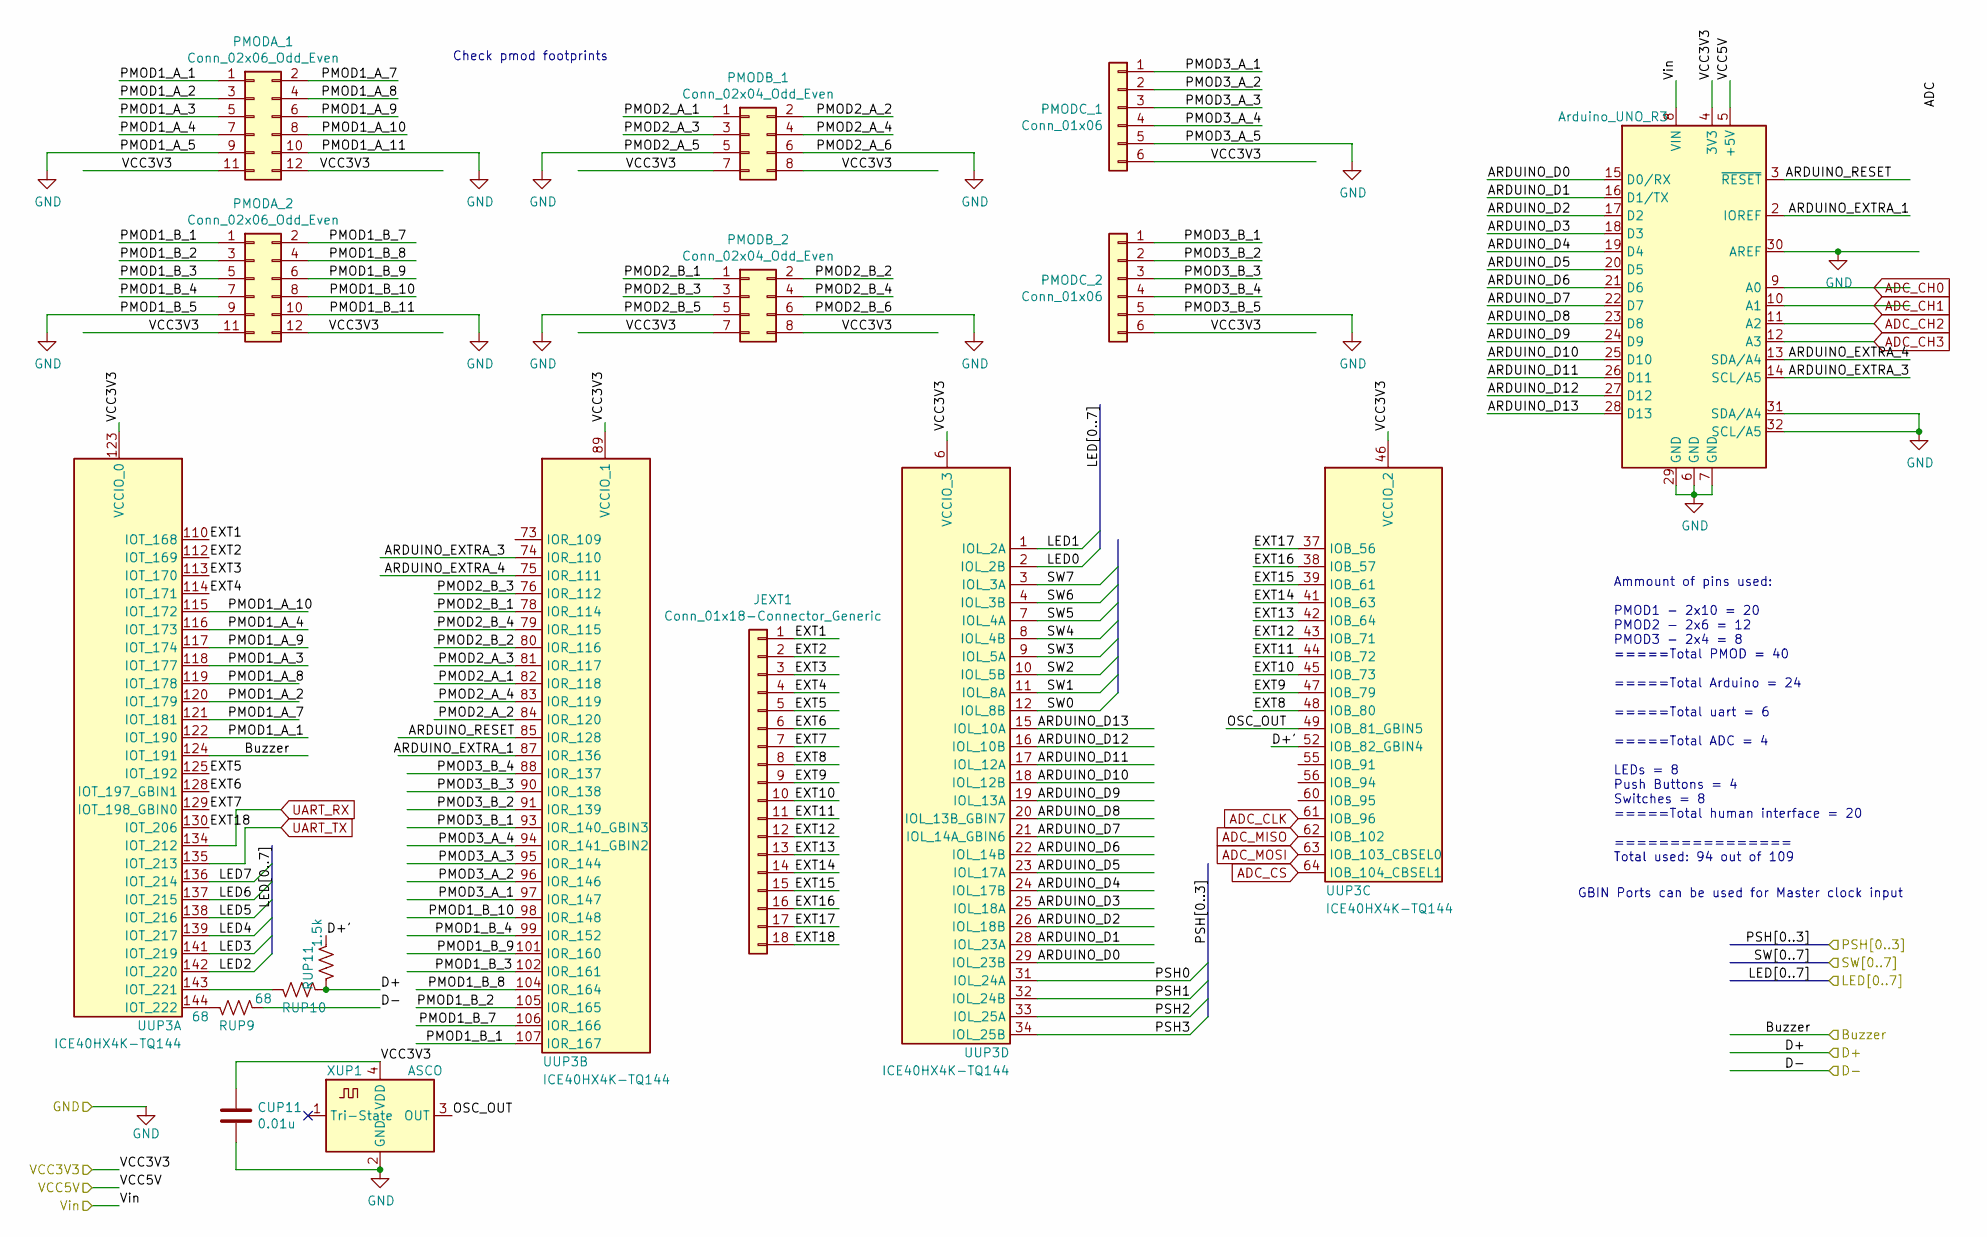
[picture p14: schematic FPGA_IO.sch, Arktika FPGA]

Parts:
A1: Arduino_UNO_R3
CUP11: 0.01u; C_0603_1608Metric_Pad1.05x0.95mm_HandSolder
JEXT1: Conn_01x18-Connector_Generic; PinHeader_1x18_P2.54mm_Vertical
PMODA_1, PMODA_2: Conn_02x06_Odd_Even; PinHeader_2x06_P2.54mm_Horizontal
PMODB_1, PMODB_2: Conn_02x04_Odd_Even; PinHeader_2x04_P2.54mm_Horizontal
PMODC_1, PMODC_2: Conn_01x06; PinHeader_1x06_P2.54mm_Horizontal
RUP9, RUP10: 68; R_0603_1608Metric_Pad1.05x0.95mm_HandSolder
RUP11: 1.5k; R_0603_1608Metric_Pad1.05x0.95mm_HandSolder
UUP3: ICE40HX4K-TQ144; TQFP-144_20x20mm_P0.5mm
XUP1: ASCO; Crystal_SMD_3225-4pin_3.2x2.5mm_HandSoldering

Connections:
/D+: RUP10.2, RUP11.2; also elsewhere on the board
/D-: RUP9.2; also elsewhere on the board
/FPGA_IO/ARDUINO_D0: A1.15 (D0/RX), UUP3.29 (IOL_23B)
/FPGA_IO/ARDUINO_D1: A1.16 (D1/TX), UUP3.28 (IOL_23A)
/FPGA_IO/ARDUINO_D2: A1.17 (D2), UUP3.26 (IOL_18B)
/FPGA_IO/ARDUINO_D3: A1.18 (D3), UUP3.25 (IOL_18A)
/FPGA_IO/ARDUINO_D4: A1.19 (D4), UUP3.24 (IOL_17B)
/FPGA_IO/ARDUINO_D5: A1.20 (D5), UUP3.23 (IOL_17A)
/FPGA_IO/ARDUINO_D6: A1.21 (D6), UUP3.22 (IOL_14B)
/FPGA_IO/ARDUINO_D7: A1.22 (D7), UUP3.21 (IOL_14A_GBIN6)
/FPGA_IO/ARDUINO_D8: A1.23 (D8), UUP3.20 (IOL_13B_GBIN7)
/FPGA_IO/ARDUINO_D9: A1.24 (D9), UUP3.19 (IOL_13A)
/FPGA_IO/ARDUINO_D10: A1.25 (D10), UUP3.18 (IOL_12B)
/FPGA_IO/ARDUINO_D11: A1.26 (D11), UUP3.17 (IOL_12A)
/FPGA_IO/ARDUINO_D12: A1.27 (D12), UUP3.16 (IOL_10B)
/FPGA_IO/ARDUINO_D13: A1.28 (D13), UUP3.15 (IOL_10A)
/FPGA_IO/ARDUINO_EXTRA_1: A1.2 (IOREF), UUP3.87 (IOR_136)
/FPGA_IO/ARDUINO_EXTRA_3: A1.14 (SCL/A5), UUP3.74 (IOR_110)
/FPGA_IO/ARDUINO_EXTRA_4: A1.13 (SDA/A4), UUP3.75 (IOR_111)
/FPGA_IO/ARDUINO_RESET: A1.3 (~RESET), UUP3.85 (IOR_128)
/FPGA_IO/Buzzer: UUP3.124 (IOT_191); also elsewhere on the board
/FPGA_IO/D+': RUP11.1, UUP3.52 (IOB_82_GBIN4)
/FPGA_IO/EXT1: JEXT1.1, UUP3.110 (IOT_168)
/FPGA_IO/EXT2: JEXT1.2, UUP3.112 (IOT_169)
/FPGA_IO/EXT3: JEXT1.3, UUP3.113 (IOT_170)
/FPGA_IO/EXT4: JEXT1.4, UUP3.114 (IOT_171)
/FPGA_IO/EXT5: JEXT1.5, UUP3.125 (IOT_192)
/FPGA_IO/EXT6: JEXT1.6, UUP3.128 (IOT_197_GBIN1)
/FPGA_IO/EXT7: JEXT1.7, UUP3.129 (IOT_198_GBIN0)
/FPGA_IO/EXT8: JEXT1.8, UUP3.48 (IOB_80)
/FPGA_IO/EXT9: JEXT1.9, UUP3.47 (IOB_79)
/FPGA_IO/EXT10: JEXT1.10, UUP3.45 (IOB_73)
/FPGA_IO/EXT11: JEXT1.11, UUP3.44 (IOB_72)
/FPGA_IO/EXT12: JEXT1.12, UUP3.43 (IOB_71)
/FPGA_IO/EXT13: JEXT1.13, UUP3.42 (IOB_64)
/FPGA_IO/EXT14: JEXT1.14, UUP3.41 (IOB_63)
/FPGA_IO/EXT15: JEXT1.15, UUP3.39 (IOB_61)
/FPGA_IO/EXT16: JEXT1.16, UUP3.38 (IOB_57)
/FPGA_IO/EXT17: JEXT1.17, UUP3.37 (IOB_56)
/FPGA_IO/EXT18: JEXT1.18, UUP3.130 (IOT_206)
/FPGA_IO/LED0: UUP3.2 (IOL_2B); also elsewhere on the board
/FPGA_IO/LED1: UUP3.1 (IOL_2A); also elsewhere on the board
/FPGA_IO/LED2: UUP3.142 (IOT_220); also elsewhere on the board
/FPGA_IO/LED3: UUP3.141 (IOT_219); also elsewhere on the board
/FPGA_IO/LED4: UUP3.139 (IOT_217); also elsewhere on the board
/FPGA_IO/LED5: UUP3.138 (IOT_216); also elsewhere on the board
/FPGA_IO/LED6: UUP3.137 (IOT_215); also elsewhere on the board
/FPGA_IO/LED7: UUP3.136 (IOT_214); also elsewhere on the board
/FPGA_IO/OSC_OUT: UUP3.49 (IOB_81_GBIN5), XUP1.3 (OUT)
/FPGA_IO/PMOD1_A_1: PMODA_1.1, UUP3.122 (IOT_190)
/FPGA_IO/PMOD1_A_2: PMODA_1.3, UUP3.120 (IOT_179)
/FPGA_IO/PMOD1_A_3: PMODA_1.5, UUP3.118 (IOT_177)
/FPGA_IO/PMOD1_A_4: PMODA_1.7, UUP3.116 (IOT_173)
/FPGA_IO/PMOD1_A_7: PMODA_1.2, UUP3.121 (IOT_181)
/FPGA_IO/PMOD1_A_8: PMODA_1.4, UUP3.119 (IOT_178)
/FPGA_IO/PMOD1_A_9: PMODA_1.6, UUP3.117 (IOT_174)
/FPGA_IO/PMOD1_A_10: PMODA_1.8, UUP3.115 (IOT_172)
/FPGA_IO/PMOD1_B_1: PMODA_2.1, UUP3.107 (IOR_167)
/FPGA_IO/PMOD1_B_2: PMODA_2.3, UUP3.105 (IOR_165)
/FPGA_IO/PMOD1_B_3: PMODA_2.5, UUP3.102 (IOR_161)
/FPGA_IO/PMOD1_B_4: PMODA_2.7, UUP3.99 (IOR_152)
/FPGA_IO/PMOD1_B_7: PMODA_2.2, UUP3.106 (IOR_166)
/FPGA_IO/PMOD1_B_8: PMODA_2.4, UUP3.104 (IOR_164)
/FPGA_IO/PMOD1_B_9: PMODA_2.6, UUP3.101 (IOR_160)
/FPGA_IO/PMOD1_B_10: PMODA_2.8, UUP3.98 (IOR_148)
/FPGA_IO/PMOD2_A_1: PMODB_1.1, UUP3.82 (IOR_118)
/FPGA_IO/PMOD2_A_2: PMODB_1.2, UUP3.84 (IOR_120)
/FPGA_IO/PMOD2_A_3: PMODB_1.3, UUP3.81 (IOR_117)
/FPGA_IO/PMOD2_A_4: PMODB_1.4, UUP3.83 (IOR_119)
/FPGA_IO/PMOD2_B_1: PMODB_2.1, UUP3.78 (IOR_114)
/FPGA_IO/PMOD2_B_2: PMODB_2.2, UUP3.80 (IOR_116)
/FPGA_IO/PMOD2_B_3: PMODB_2.3, UUP3.76 (IOR_112)
/FPGA_IO/PMOD2_B_4: PMODB_2.4, UUP3.79 (IOR_115)
/FPGA_IO/PMOD3_A_1: PMODC_1.1, UUP3.97 (IOR_147)
/FPGA_IO/PMOD3_A_2: PMODC_1.2, UUP3.96 (IOR_146)
/FPGA_IO/PMOD3_A_3: PMODC_1.3, UUP3.95 (IOR_144)
/FPGA_IO/PMOD3_A_4: PMODC_1.4, UUP3.94 (IOR_141_GBIN2)
/FPGA_IO/PMOD3_B_1: PMODC_2.1, UUP3.93 (IOR_140_GBIN3)
/FPGA_IO/PMOD3_B_2: PMODC_2.2, UUP3.91 (IOR_139)
/FPGA_IO/PMOD3_B_3: PMODC_2.3, UUP3.90 (IOR_138)
/FPGA_IO/PMOD3_B_4: PMODC_2.4, UUP3.88 (IOR_137)
/FPGA_IO/PSH0: UUP3.31 (IOL_24A); also elsewhere on the board
/FPGA_IO/PSH1: UUP3.32 (IOL_24B); also elsewhere on the board
/FPGA_IO/PSH2: UUP3.33 (IOL_25A); also elsewhere on the board
/FPGA_IO/PSH3: UUP3.34 (IOL_25B); also elsewhere on the board
/FPGA_IO/SW0: UUP3.12 (IOL_8B); also elsewhere on the board
/FPGA_IO/SW1: UUP3.11 (IOL_8A); also elsewhere on the board
/FPGA_IO/SW2: UUP3.10 (IOL_5B); also elsewhere on the board
/FPGA_IO/SW3: UUP3.9 (IOL_5A); also elsewhere on the board
/FPGA_IO/SW4: UUP3.8 (IOL_4B); also elsewhere on the board
/FPGA_IO/SW5: UUP3.7 (IOL_4A); also elsewhere on the board
/FPGA_IO/SW6: UUP3.4 (IOL_3B); also elsewhere on the board
/FPGA_IO/SW7: UUP3.3 (IOL_3A); also elsewhere on the board
/VCC3V3: A1.4 (3V3), CUP11.1, PMODA_1.11, PMODA_1.12, PMODA_2.11, PMODA_2.12, PMODB_1.7, PMODB_1.8, PMODB_2.7, PMODB_2.8, PMODC_1.6, PMODC_2.6, UUP3.6 (VCCIO_3), UUP3.30 (VCCIO_3), UUP3.46 (VCCIO_2), UUP3.57 (VCCIO_2), UUP3.89 (VCCIO_1), UUP3.100 (VCCIO_1), UUP3.123 (VCCIO_0), UUP3.131 (VCCIO_0), XUP1.4 (VDD); also elsewhere on the board
/VCC5V: A1.5 (+5V); also elsewhere on the board
/VIN: A1.8 (VIN); also elsewhere on the board
ADC_CH0: A1.9 (A0); also elsewhere on the board
ADC_CH1: A1.10 (A1); also elsewhere on the board
ADC_CH2: A1.11 (A2); also elsewhere on the board
ADC_CH3: A1.12 (A3); also elsewhere on the board
ADC_CLK: UUP3.61 (IOB_96); also elsewhere on the board
ADC_CS: UUP3.64 (IOB_104_CBSEL1); also elsewhere on the board
ADC_MISO: UUP3.62 (IOB_102); also elsewhere on the board
ADC_MOSI: UUP3.63 (IOB_103_CBSEL0); also elsewhere on the board
GND: A1.6 (GND), A1.7 (GND), A1.29 (GND), A1.30 (AREF), A1.31 (SDA/A4), A1.32 (SCL/A5), CUP11.2, PMODA_1.9, PMODA_1.10, PMODA_2.9, PMODA_2.10, PMODB_1.5, PMODB_1.6, PMODB_2.5, PMODB_2.6, PMODC_1.5, PMODC_2.5, XUP1.2 (GND); also elsewhere on the board
unnamed: RUP9.1, UUP3.144 (IOT_222)
unnamed: RUP10.1, UUP3.143 (IOT_221)
UART_RX: UUP3.134 (IOT_212); also elsewhere on the board
UART_TX: UUP3.135 (IOT_213); also elsewhere on the board

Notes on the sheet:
Ammount of pins used: PMOD1 - 2x10 = 20 PMOD2 - 2x6 = 12 PMOD3 - 2x4 = 8 =====Total PMOD = 40 =====Total Arduino = 24 =====Total uart = 6 =====Total ADC = 4 LEDs = 8 Push Buttons = 4 Switches = 8 =====Total human interface = 20 ================ Total used: 94 out of 109
GBIN Ports can be used for Master clock input
Check pmod footprints

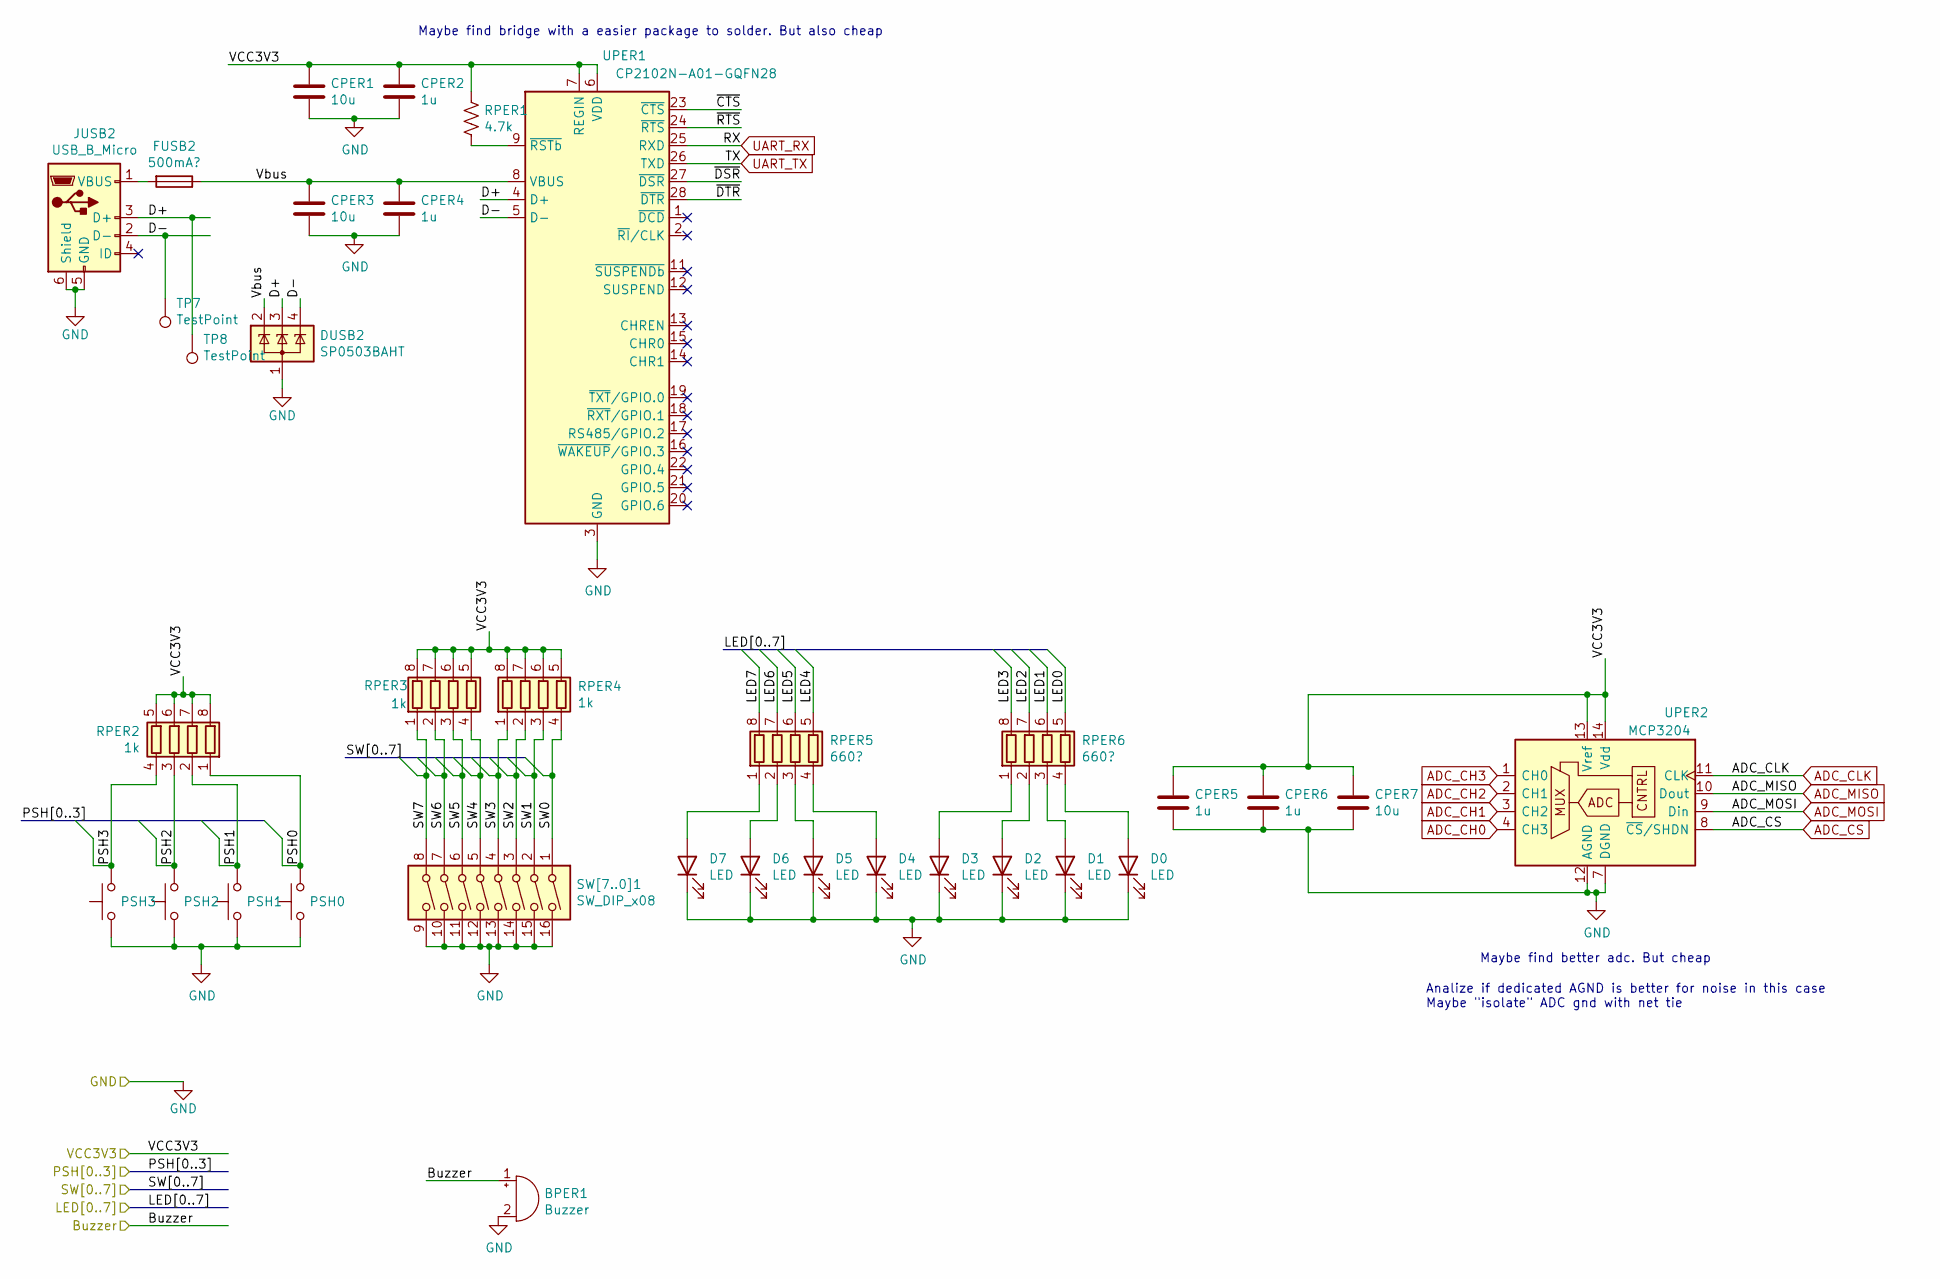
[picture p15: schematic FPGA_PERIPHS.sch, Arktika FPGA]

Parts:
BPER1: Buzzer; PinHeader_1x02_P2.54mm_Vertical
CPER1, CPER3, CPER7: 10u; C_0603_1608Metric_Pad1.05x0.95mm_HandSolder
CPER2, CPER4, CPER5, CPER6: 1u; C_0603_1608Metric_Pad1.05x0.95mm_HandSolder
D0, D1, D2, D3, D4, D5, D6, D7: LED; LED_0603_1608Metric_Pad1.05x0.95mm_HandSolder
DUSB2: SP0503BAHT; SOT-143
FUSB2: 500mA?; Fuse_1812_4532Metric_Pad1.30x3.40mm_HandSolder
JUSB2: USB_B_Micro; USB_Micro-B_Molex-105017-0001
PSH0, PSH1, PSH2, PSH3: SW_Push; SW_SPST_PTS645
RPER1: 4.7k; R_0603_1608Metric_Pad1.05x0.95mm_HandSolder
RPER2, RPER3, RPER4: 1k; R_Array_Convex_4x0603
RPER5, RPER6: 660?; R_Array_Convex_4x0603
SW[7..0]1: SW_DIP_x08; SW_DIP_SPSTx08_Slide_6.7x21.88mm_W8.61mm_P2.54mm_LowProfile
TP7, TP8: TestPoint; Pin_D0.7mm_L6.5mm_W1.8mm_FlatFork
UPER1: CP2102N-A01-GQFN28; QFN-28-1EP_4x4mm_P0.4mm_EP2.6x2.6mm
UPER2: MCP3204; SOIC-14_3.9x8.7mm_P1.27mm

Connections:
/FPGA_IO/Buzzer: BPER1.1 (-); also elsewhere on the board
/FPGA_IO/LED0: RPER6.5 (R4.2); also elsewhere on the board
/FPGA_IO/LED1: RPER6.6 (R3.2); also elsewhere on the board
/FPGA_IO/LED2: RPER6.7 (R2.2); also elsewhere on the board
/FPGA_IO/LED3: RPER6.8 (R1.2); also elsewhere on the board
/FPGA_IO/LED4: RPER5.5 (R4.2); also elsewhere on the board
/FPGA_IO/LED5: RPER5.6 (R3.2); also elsewhere on the board
/FPGA_IO/LED6: RPER5.7 (R2.2); also elsewhere on the board
/FPGA_IO/LED7: RPER5.8 (R1.2); also elsewhere on the board
/FPGA_IO/PSH0: PSH0.2, RPER2.1 (R1.1); also elsewhere on the board
/FPGA_IO/PSH1: PSH1.2, RPER2.2 (R2.1); also elsewhere on the board
/FPGA_IO/PSH2: PSH2.2, RPER2.3 (R3.1); also elsewhere on the board
/FPGA_IO/PSH3: PSH3.2, RPER2.4 (R4.1); also elsewhere on the board
/FPGA_IO/SW0: RPER4.4 (R4.1), SW[7..0]1.1; also elsewhere on the board
/FPGA_IO/SW1: RPER4.3 (R3.1), SW[7..0]1.2; also elsewhere on the board
/FPGA_IO/SW2: RPER4.2 (R2.1), SW[7..0]1.3; also elsewhere on the board
/FPGA_IO/SW3: RPER4.1 (R1.1), SW[7..0]1.4; also elsewhere on the board
/FPGA_IO/SW4: RPER3.4 (R4.1), SW[7..0]1.5; also elsewhere on the board
/FPGA_IO/SW5: RPER3.3 (R3.1), SW[7..0]1.6; also elsewhere on the board
/FPGA_IO/SW6: RPER3.2 (R2.1), SW[7..0]1.7; also elsewhere on the board
/FPGA_IO/SW7: RPER3.1 (R1.1), SW[7..0]1.8; also elsewhere on the board
/FPGA_PERIPHS/D+: DUSB2.3 (K), JUSB2.3 (D+), TP8.1, UPER1.4 (D+)
/FPGA_PERIPHS/D-: DUSB2.4 (K), JUSB2.2 (D-), TP7.1, UPER1.5 (D-)
/FPGA_PERIPHS/Vbus: CPER3.1, CPER4.1, DUSB2.2 (K), FUSB2.1, UPER1.8 (VBUS)
/FPGA_PERIPHS/~CTS: UPER1.23 (~CTS)
/FPGA_PERIPHS/~DSR: UPER1.27 (~DSR)
/FPGA_PERIPHS/~DTR: UPER1.28 (~DTR)
/FPGA_PERIPHS/~RTS: UPER1.24 (~RTS)
/VCC3V3: CPER1.1, CPER2.1, CPER5.1, CPER6.1, CPER7.1, RPER1.1, RPER2.5 (R4.2), RPER2.6 (R3.2), RPER2.7 (R2.2), RPER2.8 (R1.2), RPER3.5 (R4.2), RPER3.6 (R3.2), RPER3.7 (R2.2), RPER3.8 (R1.2), RPER4.5 (R4.2), RPER4.6 (R3.2), RPER4.7 (R2.2), RPER4.8 (R1.2), UPER1.6 (VDD), UPER1.7 (REGIN), UPER2.13 (Vref), UPER2.14 (Vdd); also elsewhere on the board
ADC_CH0: UPER2.4 (CH3); also elsewhere on the board
ADC_CH1: UPER2.3 (CH2); also elsewhere on the board
ADC_CH2: UPER2.2 (CH1); also elsewhere on the board
ADC_CH3: UPER2.1 (CH0); also elsewhere on the board
ADC_CLK: UPER2.11 (CLK); also elsewhere on the board
ADC_CS: UPER2.8 (~CS~/SHDN); also elsewhere on the board
ADC_MISO: UPER2.10 (Dout); also elsewhere on the board
ADC_MOSI: UPER2.9 (Din); also elsewhere on the board
GND: BPER1.2 (+), CPER1.2, CPER2.2, CPER3.2, CPER4.2, CPER5.2, CPER6.2, CPER7.2, D0.1 (K), D1.1 (K), D2.1 (K), D3.1 (K), D4.1 (K), D5.1 (K), D6.1 (K), D7.1 (K), DUSB2.1 (A), JUSB2.5 (GND), JUSB2.6 (Shield), PSH0.1, PSH1.1, PSH2.1, PSH3.1, SW[7..0]1.9, SW[7..0]1.10, SW[7..0]1.11, SW[7..0]1.12, SW[7..0]1.13, SW[7..0]1.14, SW[7..0]1.15, SW[7..0]1.16, UPER1.3 (GND), UPER1.29 (GND), UPER2.7 (DGND), UPER2.12 (AGND); also elsewhere on the board
unnamed: D0.2 (A), RPER6.4 (R4.1)
unnamed: D1.2 (A), RPER6.3 (R3.1)
unnamed: D2.2 (A), RPER6.2 (R2.1)
unnamed: D3.2 (A), RPER6.1 (R1.1)
unnamed: D4.2 (A), RPER5.4 (R4.1)
unnamed: D5.2 (A), RPER5.3 (R3.1)
unnamed: D6.2 (A), RPER5.2 (R2.1)
unnamed: D7.2 (A), RPER5.1 (R1.1)
unnamed: FUSB2.2, JUSB2.1 (VBUS)
unnamed: RPER1.2, UPER1.9 (~RSTb)
UART_RX: UPER1.25 (RXD); also elsewhere on the board
UART_TX: UPER1.26 (TXD); also elsewhere on the board

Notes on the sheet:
Maybe find better adc. But cheap
Maybe find bridge with a easier package to solder. But also cheap
Analize if dedicated AGND is better for noise in this case Maybe "isolate" ADC gnd with net tie

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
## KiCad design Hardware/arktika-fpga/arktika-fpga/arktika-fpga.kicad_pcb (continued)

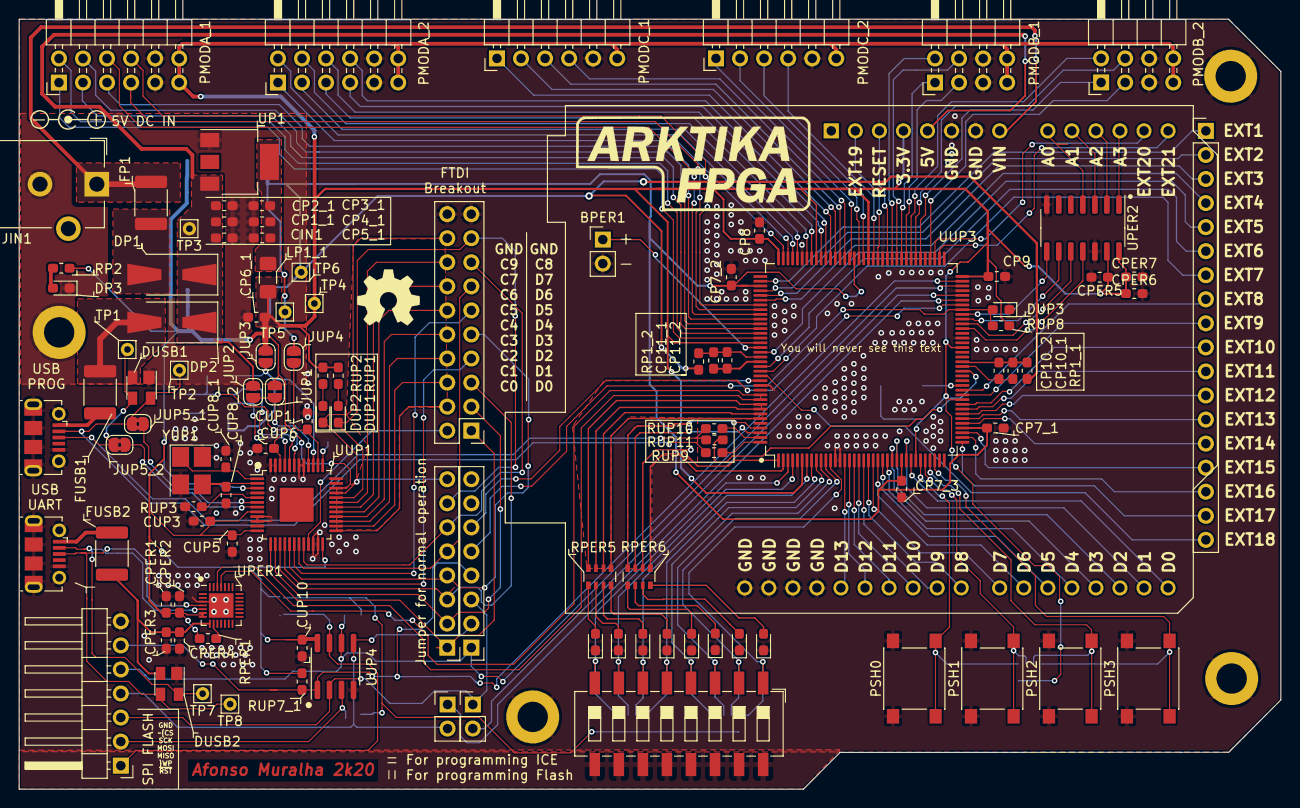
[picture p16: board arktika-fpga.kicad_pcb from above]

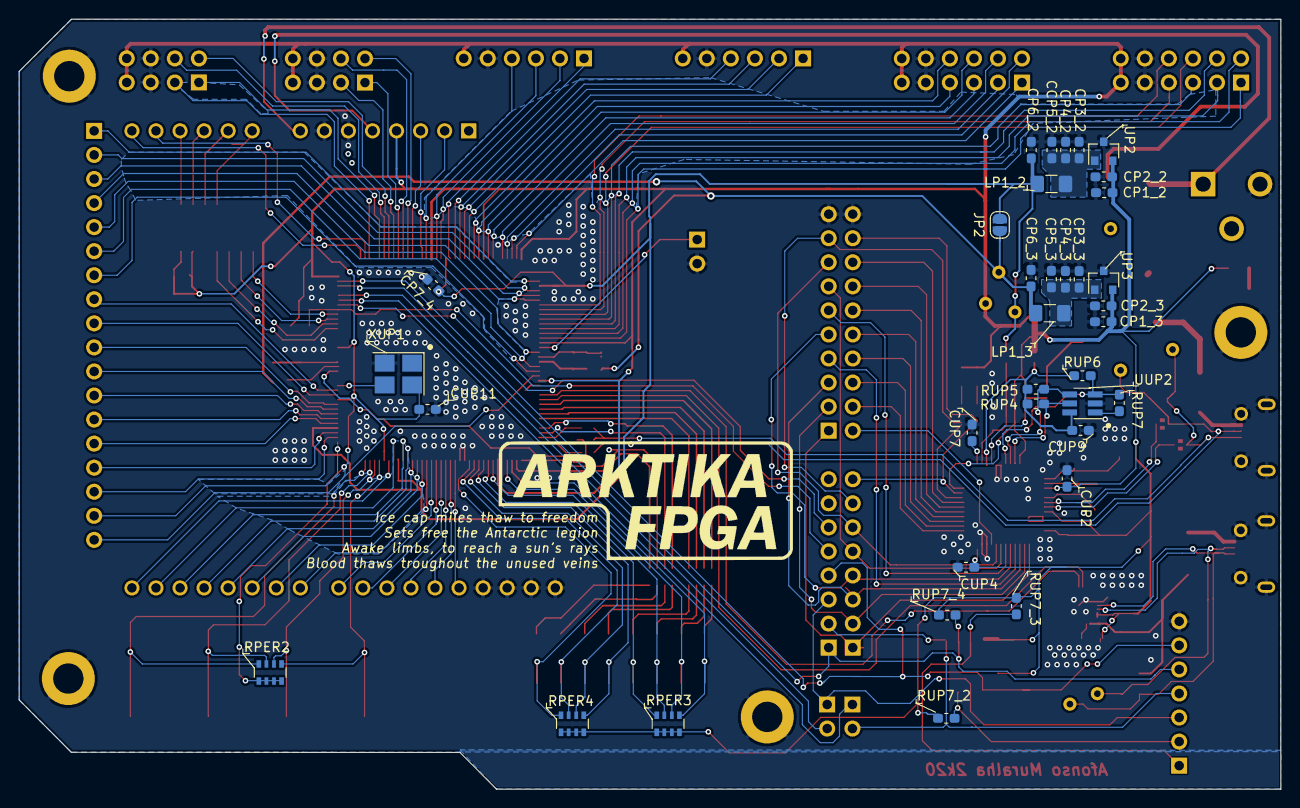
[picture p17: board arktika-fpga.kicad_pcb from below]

Board: 2 copper layers, 133.2 x 81.3 mm, 143 parts (35 on the bottom side), 178 nets.

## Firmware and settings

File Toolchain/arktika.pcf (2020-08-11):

#Board Dedicated Oscillator
set_io --warn-no-port CLK 49

#=======Board LEDs========
set_io --warn-no-port LED0 2
set_io --warn-no-port LED1 1
set_io --warn-no-port LED2 142
set_io --warn-no-port LED3 141
set_io --warn-no-port LED4 139
set_io --warn-no-port LED5 138
set_io --warn-no-port LED6 137
set_io --warn-no-port LED7 136

set_io --warn-no-port led[0] 2
set_io --warn-no-port led[1] 1
set_io --warn-no-port led[2] 142
set_io --warn-no-port led[3] 141
set_io --warn-no-port led[4] 139
set_io --warn-no-port led[5] 138
set_io --warn-no-port led[6] 137
set_io --warn-no-port led[7] 136


#========Board Switches========
set_io --warn-no-port SW0 12
set_io --warn-no-port SW1 11
set_io --warn-no-port SW2 10
set_io --warn-no-port SW3 9
set_io --warn-no-port SW4 8
set_io --warn-no-port SW5 7
set_io --warn-no-port SW6 4
set_io --warn-no-port SW7 3

set_io --warn-no-port sw[0] 12
set_io --warn-no-port sw[1] 11
set_io --warn-no-port sw[2] 10
set_io --warn-no-port sw[3] 9
set_io --warn-no-port sw[4] 8
set_io --warn-no-port sw[5] 7
set_io --warn-no-port sw[6] 4
set_io --warn-no-port sw[7] 3


#========Board Push Buttons========
set_io --warn-no-port PSH0 31
set_io --warn-no-port PSH1 32
set_io --warn-no-port PSH2 33
set_io --warn-no-port PSH3 34

set_io --warn-no-port psh[0] 31
set_io --warn-no-port psh[1] 32
set_io --warn-no-port psh[2] 33
set_io --warn-no-port psh[3] 34

#========Board EXT Header========
set_io --warn-no-port EXT1 110
set_io --warn-no-port EXT2 112
set_io --warn-no-port EXT3 113
set_io --warn-no-port EXT4 114
set_io --warn-no-port EXT5 125
set_io --warn-no-port EXT6 128
set_io --warn-no-port EXT7 129
set_io --warn-no-port EXT8 48
set_io --warn-no-port EXT9 47
set_io --warn-no-port EXT10 45
set_io --warn-no-port EXT11 44
set_io --warn-no-port EXT12 43
set_io --warn-no-port EXT13 42
set_io --warn-no-port EXT14 41
set_io --warn-no-port EXT15 39
set_io --warn-no-port EXT16 38
set_io --warn-no-port EXT17 37
set_io --warn-no-port EXT18 130

 
#========Board Arduino Headers========
set_io --warn-no-port D0 29
set_io --warn-no-port D1 28
set_io --warn-no-port D2 26
set_io --warn-no-port D3 25
set_io --warn-no-port D4 24
set_io --warn-no-port D5 23
set_io --warn-no-port D6 22
set_io --warn-no-port D7 21
set_io --warn-no-port D8 20
set_io --warn-no-port D9 19
set_io --warn-no-port D10 18
set_io --warn-no-port D11 17
set_io --warn-no-port D12 16
set_io --warn-no-port D13 15

set_io --warn-no-port ARDUINO_RESET 85 
set_io --warn-no-port EXTRA1 87
set_io --warn-no-port EXTRA2 74
set_io --warn-no-port EXTRA3 75


#========Board Buzzer Header======== 
set_io --warn-no-port BUZZER 124 


#========Board ADC Pins========
set_io --warn-no-port ADC_CLK 61
set_io --warn-no-port ADC_MISO 62
set_io --warn-no-port ADC_MOSI 63
set_io --warn-no-port ADC_CS 64

#========Board USB Pins========
set_io --warn-no-port USBP 143
set_io --warn-no-port USBP2 52
set_io --warn-no-port USBN 144
set_io --warn-no-port UART_TX 135
set_io --warn-no-port UART_RX 134


#========Board PMOD Headers========
#TODO

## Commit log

2020-07-25 Updated to readme, initial hardware files
    [FPGA.sch, Interfaces.sch, Power.sch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]
2020-07-25 Minor updates, added component search doc for development purposes
    [FPGA_IO.sch, FPGA_POWER_PROG.sch, arktika-fpga.sch]
2020-07-25 Redid the kicad project. Last one was a mess
    [FPGA.sch, FPGA_IO.sch, FPGA_POWER_PROG.sch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]
2020-07-25 Added more docs do readme, did board power
    [Power.sch, arktika-fpga.sch]
2020-07-26 Started doing usb and programming
    [Power.sch, Usb-and-prog.sch, arktika-fpga.sch]
2020-07-26 Added configuration for power regulation and programming nets
    [Usb-and-prog.sch]
2020-07-26 Added misc components to the usb and prog schematic
    [Usb-and-prog.sch, arktika-fpga.sch]
2020-07-28 Added designators, some io, and some peripherals
    [FPGA_IO.sch, FPGA_PERIPHS.sch, Power.sch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]
2020-07-28 Assigned some footprints to components
    [FPGA_PERIPHS.sch, Power.sch, Usb-and-prog.sch]
2020-07-29 Minor fixes
    [FPGA_PERIPHS.sch, Power.sch]
2020-07-29 Minor fixes on fpga peripherals
    [FPGA_PERIPHS.sch]
2020-07-30 Minor fixes, added peripheral buses, added annotations and added crystal datasheets
    [FPGA_IO.sch, FPGA_PERIPHS.sch, Power.sch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]
2020-07-30 Added alternate power intput. Update some designators. Added fpga crystal
    [FPGA_IO.sch, FPGA_PERIPHS.sch, Power.sch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]
2020-07-30 Added fuse to usb peripheral, other minor changes
    [FPGA_IO.sch, FPGA_PERIPHS.sch, Power.sch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]
2020-07-30 Forgot to change fusb2 designator
    [FPGA_PERIPHS.sch]
2020-07-30 Updated eeprom info in component search, added missing bp cap to eeprom
    [Usb-and-prog.sch]
2020-07-30 Misc changes and fixes
    [FPGA_IO.sch, FPGA_PERIPHS.sch, Power.sch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]
2020-07-31 Addded new hybrid crystal footprint, fixed missing footprints, created layout file for testing
    [FPGA_IO.sch, FPGA_PERIPHS.sch, Power.sch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]
2020-07-31 Added fuses library to project. Minor changes
    [arktika-fpga.kicad_pcb]
2020-08-01 Misc schematic changes. Preliminary layout almost complete
    [FPGA_IO.sch, FPGA_PERIPHS.sch, Power.sch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]
2020-08-02 Major routing updates. Did work on silkscreen. Optimized io placing. Misc changes
    [FPGA_IO.sch, Power.sch, Usb-and-prog.sch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]
2020-08-02 Added more IO
    [FPGA_IO.sch, FPGA_PERIPHS.sch, arktika-fpga.kicad_pcb]
2020-08-02 Finished routing, did gnd planes, added more silkscreen and some manual via stitching. Pre-final layout.
    [FPGA_IO.sch, FPGA_PERIPHS.sch, Power.sch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]
2020-08-03 Minor layout fixes
    [arktika-fpga.kicad_pcb]
2020-08-03 Fixed minor drc errors. removed usb jumpers and added needed resistors
    [FPGA_IO.sch, Power.sch, arktika-fpga.kicad_pcb]
2020-08-03 Minor layout changes
    [arktika-fpga.kicad_pcb]
2020-08-04 Added silkscreen art and added media folder with the same art
    [FPGA_IO.sch, FPGA_PERIPHS.sch, Misc.sch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]
2020-08-04 Minor layout fixes. Added new micro usb connector footprint and link. Misc silk changes
    [FPGA_PERIPHS.sch, Power.sch, arktika-fpga.kicad_pcb]
2020-08-04 Added pcbway logo to top silkscreen
    [arktika-fpga.kicad_pcb]
2020-08-04 misc changes, exported test gerbers
    [arktika-fpga-B_Mask.gbs, arktika-fpga-B_Paste.gbp, arktika-fpga-B_SilkS.gbo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]
2020-08-05 Exported final gerbers. Sent to fab
    [FPGA_IO.sch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]
2020-08-06 Fixed clearance error on design. Sent to fab
    [arktika-fpga-B_Mask.gbs, arktika-fpga-B_Paste.gbp, arktika-fpga-B_SilkS.gbo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]
2020-08-07 Fixed gerber format issue with manufacturer
    [arktika-fpga-B_Mask.gbs, arktika-fpga-B_Paste.gbp, arktika-fpga-B_SilkS.gbo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]
2020-08-11 Added initial files for the toolchain information. Added basic example. Added pcf board file
2020-08-24 Generated gerbers without pcbway branding. Sent do fab
    [arktika-fpga-B_Mask.gbr, arktika-fpga-B_Mask.gbs, arktika-fpga-B_Paste.gbp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]
2020-09-22 exported schematics pdf
2020-09-28 Fixed flash CS net
    [Usb-and-prog.sch, arktika-fpga.kicad_pcb]
